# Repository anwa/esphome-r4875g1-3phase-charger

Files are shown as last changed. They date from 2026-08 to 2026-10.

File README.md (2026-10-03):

# 3-Phase Huawei R4875G1 Battery Charger Controller

ESPHome-based controller for three Huawei R4875G1 rectifiers operated as a coordinated three-phase battery charger with a common parallel DC output.

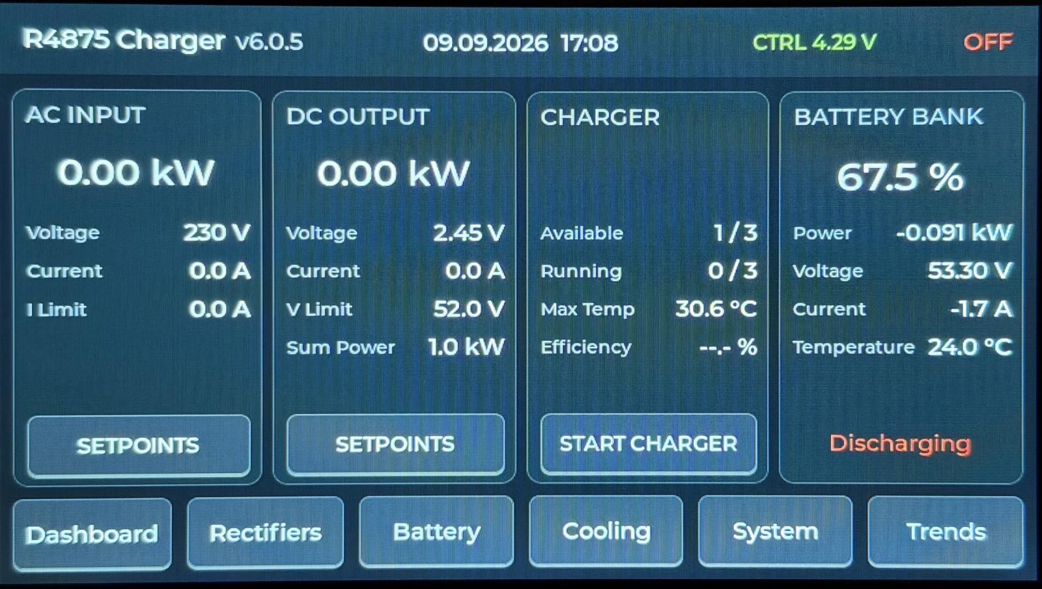
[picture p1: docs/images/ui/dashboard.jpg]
V6 shared charger dashboard


<p align="center"><em>Shared V6 Dashboard running on the Charger Controller.</em></p>

The V6 firmware generation uses two coordinated targets based on the **Waveshare ESP32-S3-Touch-LCD-7**:

- the Charger Controller, physically attached to the rectifiers and responsible for CAN, charger control, safety and local blackstart
- the Remote HMI, which uses the same shared Dashboard, Rectifiers, Battery, System, Cooling and Trends presentation while receiving authoritative charger state and sending HMI command requests through Home Assistant

Remote HMI charger commands use Home Assistant transport and remain subject to authoritative validation and execution by the Charger Controller.

A Remote HMI is paired with a Charger Controller through one configurable Home Assistant entity prefix. The individual Dashboard telemetry, setpoint and command entity IDs are derived from that prefix, so pairing another charger does not require editing every Home Assistant entity mapping.

The Charger Controller currently provides:

- local charger control
- CAN communication with three independent R4875G1 rectifiers
- automatic discovery and reconnect handling
- capability-aware current limiting
- thermal protection and derating
- network-independent local blackstart operation
- a 7-inch LVGL touchscreen interface
- a direct-GPIO backup rotary encoder for network-independent setpoint and charger power control
- external compartment cooling
- controller backup-battery monitoring
- Home Assistant solar-battery-bank monitoring
- Home Assistant, MQTT and ESPHome web integration

The charger core is intentionally designed to remain operational without Wi-Fi, Home Assistant, MQTT or Internet access.

For detailed runtime and state-machine behavior, see [`R4875G1_CONTROL_FLOWS.md`](R4875G1_CONTROL_FLOWS.md).

For package ownership and firmware architecture, see [`packages/README.md`](packages/README.md).

Repository development rules are defined in [`AGENTS.md`](AGENTS.md) and the [`rules/`](rules/) directory.

> [!WARNING]
> This project controls equipment connected to mains voltage and a high-current
> DC battery bus.
>
> Three Huawei R4875G1 rectifiers can represent roughly 12 kW of charging power
> and more than 200 A on a 48–58 V DC bus.
>
> Firmware is not a substitute for correctly designed fuses, breakers,
> disconnects, BMS protection, earthing, isolation, conductor sizing and other
> required electrical safety measures.

---

## System Architecture

The intended installation uses one rectifier per AC phase while all three DC outputs feed the same battery/DC bus.

```text
Three-phase AC
    │
    ├── L1 -> R4875G1 Unit 1 ──┐
    ├── L2 -> R4875G1 Unit 2 ──┼── Common DC bus / battery
    └── L3 -> R4875G1 Unit 3 ──┘
                 │
                 └── Shared CAN bus
                          │
                          ▼
              Waveshare ESP32-S3 Controller
```

All rectifiers use:

```text
CAN bit rate:       125 kbit/s
CAN identifiers:    29-bit extended
DC voltage command: shared
DC current command: common per-unit request
```

Each rectifier maintains its own communication, lifecycle, discovery, thermal and telemetry state.

---

## V6 Hardware Targets

The current firmware targets:

```text
Waveshare ESP32-S3-Touch-LCD-7
ESP32-S3 N16R8
16 MB Flash
8 MB PSRAM
7-inch 800 × 480 RGB LCD
GT911 capacitive touchscreen
CH422G onboard I/O expander
onboard CAN transceiver
```

The controller uses the onboard ESP32-S3 TWAI peripheral and CAN transceiver.
No external SN65HVD230 module is required by the V6 hardware.

### External I2C Architecture

The shared controller I2C bus uses:

```text
GPIO8  -> SDA
GPIO9  -> SCL
400 kHz
```

External I2C peripherals use a dedicated second physical I2C bus. This isolates their addresses from the Waveshare onboard CH422G and allows the onboard display/touch bus to remain at 400 kHz.

```text
ESP32-S3
│
├── Onboard I2C — GPIO8 / GPIO9 — 400 kHz
│   ├── CH422G
│   └── GT911 touchscreen
│
└── External I2C — GPIO44 / GPIO43
    ├── MCP23017 @ 0x20
    │   ├── GPA0 -> external fan power enable
    │   ├── GPA1 -> Cooling Fan 1 tachometer
    │   └── GPA2 -> Cooling Fan 2 tachometer
    ├── BME280 @ 0x76
    │   ├── rectifier-compartment temperature
    │   ├── rectifier-compartment humidity
    │   └── station pressure
    └── EMC2101 @ 0x4C
        ├── external fan PWM
        └── Cooling Fan 3 tachometer
```

The MCP23017 is used without a dedicated ESP32 interrupt line; INTA and INTB are intentionally left unconnected.

The backup rotary encoder is connected directly to the ESP32-S3 rather than through I2C:

```text
GPIO11 -> Encoder S1 / A
GPIO12 -> Encoder S2 / B
GPIO13 -> Encoder KEY
```

GPIO11, GPIO12 and GPIO13 are the Waveshare TF-card SPI pins, so the TF-card interface is unavailable while the backup encoder uses them.

The BME280 station pressure is exposed directly. A second pressure entity publishes the standard-atmosphere sea-level equivalent for the fixed 316 m installation altitude.

Unused MCP23017 pins remain available for future expansion.

---

## CAN Communication

The three Huawei rectifiers share one CAN bus.

The firmware implements independent per-unit communication state and explicit rectifier lifecycle handling:

```text
OFFLINE
   │
   │ CAN communication detected
   ▼
DISCOVERING
   │
   │ required discovery completed
   │ active setpoints restored
   ▼
ONLINE
```

A rectifier that loses valid communication returns to `OFFLINE`.

Normal high-rate telemetry polling is restricted to `ONLINE` units.

`OFFLINE` units are probed at a much lower rate using single-shot CAN transmission so an absent rectifier cannot continuously force the ESP32 TWAI controller toward `BUS_OFF`.

The firmware also implements explicit TWAI recovery if the complete physical CAN network disappears.

### Discovery

Discovery retrieves information including:

- static rectifier identification properties
- maximum DC-current capability
- shelf/address information

Discovery traffic is serialized so only one discovery operation owns the CAN bus at a time.

A successfully rediscovered unit receives the currently active DC voltage and current commands before its lifecycle returns to `ONLINE`.

---

## Charger Control

The controller manages three rectifiers as one coordinated charger while preserving independent per-unit safety and communication state.

Supported charger-wide controls include:

```text
Active DC voltage
Active per-unit DC current
Nominal three-unit DC power target
START
STOP
Fallback DC voltage
Fallback DC current
```

The nominal DC power target is converted into a common per-unit current request.

The requested current and the actually applied current are intentionally kept separate.

The final applied current is limited by:

```text
min(
    requested current,
    effective hardware capability,
    thermal current limit
)
```

This allows the requested charger target to remain unchanged while hardware or thermal protection temporarily reduces the current actually sent to the rectifiers.

---

## Capability-Aware Current Limiting

R4875G1 variants can report different maximum-current capabilities.

The controller therefore discovers the capability of each reachable unit and derives a safe shared limit.

The basic policy is:

```text
No reachable rectifier
    -> conservative fail-safe current ceiling

Reachable rectifier with unknown capability
    -> conservative fail-safe current ceiling

All reachable capabilities known
    -> effective ceiling = lowest reachable capability
```

Command scaling is derived independently from the detected rectifier capabilities so mixed-capability installations remain fail-safe.

A diagnostic entity reports capability mismatches between simultaneously reachable rectifiers.

---

## Thermal Protection

Each rectifier has an independent thermal state:

```text
NORMAL
WARNING_1
WARNING_2
LOCKOUT
```

The current configuration uses staged derating:

```text
70 °C -> first warning / reduced current
80 °C -> stronger current reduction
90 °C -> individual overtemperature shutdown
```

Hysteresis prevents rapid state oscillation while temperatures fall.

A thermal lockout is not cleared by missing or stale telemetry. Valid temperature data must confirm that the rectifier has returned to a safe temperature.

The shared thermal current ceiling is derived from the most restrictive active per-unit thermal state.

---

## Local Blackstart

Core charger operation is designed to remain available without network services.

Blackstart does not depend on:

```text
Home Assistant
MQTT
Wi-Fi
Internet access
```

Before a rectifier receives a START command, the controller verifies that it:

```text
is lifecycle ONLINE
has fresh CAN communication
reports explicit power state OFF
has valid output-temperature telemetry
is below the configured overtemperature trip threshold
has no active overtemperature lockout
```

Only units passing all checks receive the ON command.

STOP remains unrestricted.

This allows a partially available charger to remain controllable while preventing unknown or unsafe units from being started.

---

## Local User Interface

The controller uses the Waveshare 7-inch 800 × 480 RGB display with GT911 capacitive touch.

The display backlight is automatically disabled after the target-specific LVGL idle timeout while charger control and telemetry continue running normally. Touching and releasing the sleeping touchscreen always wakes the display without activating the control underneath the wake-up touch.

Each V6 target may optionally import its own Home Assistant occupancy/motion entity. Active motion wakes the display immediately and keeps the existing LVGL inactivity timer alive. When motion ends, the same configured idle timeout starts again. If no motion package is composed for a target, the original touch and idle-timeout behavior is unchanged. Home Assistant `unknown`, `unavailable` or connection loss is treated as no motion.

The LVGL interface contains six primary functional pages:

```text
Dashboard
Rectifiers
Battery
System
Cooling
Trends
```

The Rectifiers page also provides one shared hierarchical detail view for Units 1, 2 and 3.

### Dashboard

The Dashboard uses four equal-width overview cards for AC input, DC output, charger state and the external solar battery bank.

It provides charger-wide operating information including:

```text
AC input power
AC voltage
AC current
AC current limit
DC output power
DC voltage
combined DC current
active DC voltage limit
nominal total DC power target
available rectifier count
running rectifier count
highest rectifier output temperature
conversion efficiency
charger START/STOP state
solar battery-bank SOC
solar battery-bank power
solar battery-bank voltage
solar battery-bank current
solar battery-bank temperature
solar battery-bank operating state
```

AC and DC setpoints are edited through dedicated modal dialogs opened from the corresponding Dashboard cards.

Solar battery-bank information is imported from Home Assistant for monitoring only. Missing Home Assistant battery telemetry is shown explicitly and does not affect charger control or safety behavior.

### Rectifiers

The Rectifiers page provides one overview card for each unit.

Each rectifier maintains independent:

```text
lifecycle state
power state
CAN state
AC telemetry
DC telemetry
temperature
internal fan telemetry
```

Selecting a unit opens the shared Rectifier Detail page.

### Rectifier Detail

The detail view exposes extended per-unit information including:

```text
AC voltage
AC current
AC power
AC frequency
DC voltage
DC current
DC power
input temperature
output temperature
internal fan RPM
internal fan target duty
internal fan minimum duty
maximum-current capability
operating hours
fallback voltage
fallback current
```

One LVGL page is reused dynamically for all three rectifiers.

### Battery

The Battery page provides one monitoring card for each of four parallel solar-battery units. The same page layout and runtime are used by the Charger Controller and Remote HMI through the shared Battery UI model.

Each card displays:

```text
voltage
current
power
state of charge
temperature
cell drift
warning state
fault state
```

A consolidated per-battery status shows:

```text
HA OFFLINE
NO DATA
OK
WARNING
FAULT
```

`HA OFFLINE` indicates that no Home Assistant state-subscription connection is available.
`NO DATA` indicates that Home Assistant is connected but one or more required battery entities are unavailable or invalid.

Fault has priority over warning. Missing or invalid Home Assistant data is displayed explicitly instead of being treated as a healthy battery state.

All solar-battery telemetry is monitoring-only. It does not participate in charger setpoint calculation, START eligibility, thermal protection, CAN control or other charger safety decisions.

### Cooling

The Cooling page displays the shared rear-compartment environmental data and internal rectifier-fan telemetry.

External chassis-fan control is implemented independently by `packages/cooling.yaml`.

### System

The System page is shared by the Charger Controller and Remote HMI. It combines diagnostics measured locally on the active display controller with authoritative rectifier lifecycle state from the shared UI model.

```text
local network state
local Wi-Fi signal
local uptime
local CPU temperature
local memory/runtime information
local backup-battery voltage and state of charge
rectifier lifecycle status
```

On the Remote HMI, local device diagnostics remain available independently of Home Assistant. Rectifier state still follows the Charger Controller through Home Assistant and the shared UI-model boundary.

### Trends

Five independent sixty-minute ring buffers are maintained continuously:

```text
Combined DC Power
Combined DC Current
Average DC Voltage
Highest Rectifier Output Temperature
Rectifier Compartment Temperature
```

Sampling uses:

```text
10-second interval
360 samples
60-minute history
```

The chart time axis uses ten-minute divisions labeled from `-60 min` through `-10 min` and `now`.

Combined DC current and average DC voltage share one dual-axis chart. Current uses the left Y axis in amperes and voltage uses the right Y axis in volts, while both series use the same sixty-minute time base.

Invalid source values are preserved as gaps instead of being converted to artificial zero values.

---

## Backup Rotary Encoder and Blackstart Control

The Charger Controller uses a mechanical rotary encoder connected directly to ESP32-S3 GPIOs:

```text
GPIO11 -> Encoder S1 / A
GPIO12 -> Encoder S2 / B
GPIO13 -> Encoder KEY
```

The native ESPHome `rotary_encoder` component decodes the two quadrature channels with one output step per complete quadrature cycle. The physical encoder direction is mapped so clockwise rotation increases the active edit value.

The backup interaction is intentionally independent from normal touchscreen navigation:

```text
short press 1 -> edit charger-wide DC voltage
rotation      -> adjust voltage in 0.1 V steps
short press 2 -> edit nominal DC sum power
rotation      -> adjust power in 0.1 kW steps
short press 3 -> apply both pending setpoints

long press while idle -> request charger START or STOP
15 s inactivity       -> discard pending edits
```

Setpoint saves and charger power requests reuse the authoritative Charger Controller command paths. The encoder does not implement separate CAN or safety logic, and normal START eligibility remains authoritative.

The Controller-only LVGL overlay provides visual feedback while the display is available, but the encoder state machine and charger command path do not depend on touchscreen input, Home Assistant, MQTT or Internet access.

---

## External Cooling System

The external chassis cooling system is independent of the internal fans built into the Huawei rectifiers.

Three external fans are supported.

```text
MCP23017 GPA0 -> common fan-supply enable
MCP23017 GPA1 -> Fan 1 tachometer
MCP23017 GPA2 -> Fan 2 tachometer

EMC2101 PWM   -> common four-pin fan PWM
EMC2101 TACH  -> Fan 3 tachometer
```

Every fan retains its own tachometer signal.

The EMC2101 generates the shared hardware PWM signal at approximately:

```text
25.7 kHz
```

Cooling Fan 3 ventilates the rear rectifier compartment where the BME280 temperature/humidity/pressure sensor is installed.

### Web Controls and EMC2101 Telemetry

The ESPHome Web UI exposes the external cooling controls and EMC2101 telemetry:

```text
Cooling Fan Automatic
Cooling Fan Power
Cooling Fan Manual PWM
Cooling Fan PWM Actual
Cooling Fan Controller Temperature
Cooling Fan 1 RPM
Cooling Fan 2 RPM
Cooling Fan 3 RPM
```

`Cooling Fan Controller Temperature` reports the EMC2101 internal chip temperature. `Cooling Fan PWM Actual` reports the PWM duty cycle read back from the EMC2101 controller; it represents the programmed hardware setting rather than an independent measurement of the electrical PWM waveform.

Automatic and manual PWM control maintain separate state. While `Cooling Fan Automatic` is enabled, the compartment-temperature controller drives the EMC2101 PWM output directly and the manual PWM value remains stored without affecting the active output. When automatic mode is disabled, the stored `Cooling Fan Manual PWM` value is applied immediately and subsequent slider changes control the PWM output directly.

`Cooling Fan Power` controls the common external fan supply independently and remains available for manual operation when automatic mode is disabled.

### Automatic Cooling

Automatic cooling is enabled by default.

The current temperature curve is:

| Compartment temperature | Fan command |
| --- | ---: |
| `< 30 °C` | OFF / 0 % |
| `30–34.9 °C` | 35 % |
| `35–39.9 °C` | 45 % |
| `40–44.9 °C` | 60 % |
| `45–49.9 °C` | 80 % |
| `>= 50 °C` | 100 % |

Downward transitions use hysteresis.

If compartment-temperature telemetry becomes unavailable, the cooling system fails safe by enabling the external fans at 100 %.

---

## Local Display Backup Battery

Both V6 Waveshare display controllers support a local 1S lithium backup battery through the J3 battery connector.

The board provides an existing divider:

```text
VBAT -> 200 kΩ -> TP1 -> 100 kΩ -> GND
```

TP1 is externally connected to:

```text
J8 pin 3 / AD -> GPIO6
```

The ADC therefore sees one third of the battery voltage and the firmware restores the actual value using a factor of 3.

The measured voltage is filtered and exposed with a target-specific name:

```text
Controller Battery Voltage
Remote HMI Battery Voltage
```

A second sensor derives an approximate voltage-based state of charge:

```text
Controller Battery State of Charge
Remote HMI Battery State of Charge
```

The SOC value is intended for monitoring only. It is not a replacement for coulomb counting or a dedicated fuel-gauge IC.

---

## Solar Battery Bank Monitoring

Both V6 targets import monitoring data for an external four-unit solar battery bank from Home Assistant through the ESPHome native API.

All configurable Home Assistant entity mappings are centralized in:

```text
packages/shared/battery-bank.yaml
```

The imported aggregate bank data includes:

```text
voltage
current
power
state of charge
temperature
operating state
```

Each of the four individual battery units provides:

```text
voltage
current
power
state of charge
temperature
cell drift
warning state
fault state
```

The Home Assistant battery-bank and individual battery power entities are normalized internally from watts to kilowatts.

Battery warning and fault entities are imported as text states so `on`, `off`, `unknown` and `unavailable` remain distinguishable. After source validation, the shared Battery UI backend normalizes valid warning and fault states to boolean values in the target-neutral UI model.

Home Assistant battery telemetry is intentionally isolated from charger control. The charger remains locally operational when Wi-Fi or Home Assistant is unavailable.

---

## Network Interfaces

Network services provide additional monitoring and control but are not part of the local charger safety path.

The firmware integrates:

```text
ESPHome native API
MQTT
ESPHome Web Server
OTA
SNTP time synchronization
```

Home Assistant can therefore expose charger telemetry, diagnostics, setpoints and control entities while local operation remains independent.

---

## Firmware Architecture

The V6 generation is assembled from two root configurations plus shared and target-specific ESPHome packages.

```text
r4875g1-3phase-charger.yaml
r4875g1-remote-hmi.yaml
trend_helpers.h

packages/
├── version.yaml
├── controls.yaml
├── cooling.yaml
├── display.yaml
├── rectifier-shared.yaml
├── rectifier-unit.yaml
│
├── shared/
│   ├── core.yaml
│   ├── hardware.yaml
│   ├── local-diagnostics.yaml
│   ├── ui-model.yaml
│   ├── ui-contract.yaml
│   └── battery-monitoring.yaml
│
├── controller/
│   ├── hardware.yaml
│   ├── mqtt.yaml
│   ├── ui-backend.yaml
│   ├── ui-rectifier-backend.yaml
│   └── ui-commands.yaml
│
├── remote-hmi/
│   ├── connection-status.yaml
│   ├── ha-entity-map.yaml
│   ├── ha-backend.yaml
│   ├── rectifier-backend.yaml
│   └── ui-commands.yaml
│
├── display/
│   ├── shared-hmi.yaml
│   ├── shared-dashboard.yaml
│   ├── shared-rectifiers.yaml
│   ├── shared-battery.yaml
│   ├── shared-system.yaml
│   ├── shared-cooling.yaml
│   ├── shared-trends.yaml
│   ├── shared-navigation.yaml
│   └── pages/
│
└── rectifier-can/
    └── parameterized CAN receive handlers
```

### Package Responsibilities

| Package | Responsibility |
| --- | --- |
| `version.yaml` | coordinated V6 firmware version source of truth |
| `shared/core.yaml` | shared ESP32 platform, network, API, web, OTA and time services |
| `shared/hardware.yaml` | shared Waveshare board peripherals and local backup-battery monitoring |
| `shared/ui-model.yaml` | target-neutral state consumed by the shared HMI |
| `shared/battery-monitoring.yaml` | shared Home Assistant solar-battery monitoring and UI-model backends |
| `controller/hardware.yaml` | Charger Controller CAN, external I2C and charger-side hardware |
| `controller/ui-backend.yaml` | publishes authoritative local charger state into the shared UI model |
| `controller/ui-commands.yaml` | executes shared HMI command intents on the Charger Controller |
| `remote-hmi/ha-backend.yaml` | imports authoritative Charger Controller state through Home Assistant |
| `remote-hmi/ui-commands.yaml` | transports shared HMI command intents through Home Assistant |
| `remote-hmi/connection-status.yaml` | persistent Remote HMI Home Assistant connectivity presentation |
| `controls.yaml` | charger-wide user setpoints and controls |
| `cooling.yaml` | Charger Controller external chassis-fan control and RPM monitoring |
| `display.yaml` | Charger Controller aggregation of the shared display packages |
| `display/shared-hmi.yaml` | shared display infrastructure, presentation state, header and local trend history |
| `display/shared-*.yaml` | shared page presentation/runtime compositions for both V6 targets |
| `display/shared-navigation.yaml` | shared six-page bottom navigation |
| `rectifier-shared.yaml` | shared lifecycle, safety, discovery, CAN scheduling and control |
| `rectifier-unit.yaml` | parameterized per-unit state and telemetry |
| `rectifier-can/*.yaml` | parameterized CAN receive handlers |
| `trend_helpers.h` | native LVGL chart declarations used by the shared Trends runtime |

The detailed ownership model is documented in [`packages/README.md`](packages/README.md).

---

## Display Architecture

Both V6 targets use the same shared LVGL presentation. Target-specific backends translate their native state into the shared UI model, and shared page runtimes consume only that target-neutral model.

```text
                         Shared LVGL HMI
                               │
                               ▼
                       Shared UI model
                               │
                ┌──────────────┴──────────────┐
                ▼                             ▼
      Charger Controller backend       Remote HMI backend
                │                             │
                ▼                             ▼
       Local runtime / CAN          Home Assistant entities
```

The shared display composition contains:

```text
shared-hmi
shared-dashboard
shared-rectifiers
shared-battery
shared-system
shared-cooling
shared-trends
shared-navigation
```

Only the currently visible page receives normal page-specific display refreshes. Persistent header state, command-transition state, local backup-battery presentation and local trend sampling continue independently on each target.

---

## Building

The two V6 ESPHome root configurations are:

```text
r4875g1-3phase-charger.yaml
r4875g1-remote-hmi.yaml
```

Validate and compile the Charger Controller with:

```bash
esphome config r4875g1-3phase-charger.yaml
esphome compile r4875g1-3phase-charger.yaml
```

Validate and compile the Remote HMI with:

```bash
esphome config r4875g1-remote-hmi.yaml
esphome compile r4875g1-remote-hmi.yaml
```

Changes to shared V6 HMI code or shared target contracts must be validated against both targets. Hardware-dependent behavior should also be tested on the affected physical target after successful compilation.

---

## Versioning

The firmware version has exactly one source of truth:

```text
packages/version.yaml
```

Do not duplicate the current firmware version in documentation.

Version changes follow:

```text
rules/versioning.md
```

Pure documentation and repository-cleanup changes do not require a firmware version increment unless they also change runtime behavior.

---

## Repository Development Rules

AI-assisted and human development follows the repository rules in:

```text
AGENTS.md
rules/
```

`AGENTS.md` is the entry point for agents.

All human-readable repository content created or substantially modified by the project is written in English.

The repository rules define:

```text
development workflow
Git workflow
versioning
documentation
YAML comment style
```

---

## V4 Hardware Variant

The previous ESP32-S3-DevKitC-1 hardware implementation remains maintained separately on:

```text
v4-maintenance
```

V4 is a permanent hardware variant rather than the active V6 controller target.

Changes that are genuinely shared between both hardware generations may be ported when appropriate, but V6-specific display, I/O and hardware assumptions must not be applied blindly to the V4 branch.

---

## Related Projects and References

The following projects and documentation were particularly useful during the development and verification of the R4875G1 Charger Controller:

- [CAN-BUS-control-R4875G1-with-ESPHome-and-MQTT](https://github.com/mjpalmowski/CAN-BUS-control-R4875G1-with-ESPHome-and-MQTT)
  This project originally grew from the Huawei R4875G1 CAN and ESPHome work published by **mjpalmowski**. It provided important groundwork for Huawei CAN protocol research, telemetry decoding, control commands, property and capability discovery, and ESPHome integration.

- [patagonaa/huawei-r48xx](https://github.com/patagonaa/huawei-r48xx)
  Extensive R48xx-series documentation covering connectors, mechanical models, CAN protocol details, register behavior, software-address negotiation and model-specific observations. Its 3D PSU and case models also provided useful reference geometry for the charger's mechanical enclosure development.

- [craigpeacock/Huawei_R4850G2_CAN](https://github.com/craigpeacock/Huawei_R4850G2_CAN)
  Earlier public CAN protocol research for Huawei R48xx rectifiers and an additional useful reference while validating protocol behavior.

The Controller implementation in this repository has since evolved into a dedicated three-unit charger with independent per-unit lifecycle management, local and network-independent control, automatic CAN recovery, capability-aware current limiting, thermal protection, local blackstart operation, a shared touchscreen HMI architecture and external cooling management.

The implementation is independently maintained and contains additional multi-rectifier lifecycle, reconnect, capability, thermal, blackstart and HMI behavior specific to this project.

---

## Disclaimer

This repository is provided for development and experimentation with Huawei R4875G1 rectifiers.

Anyone building or operating hardware based on this project is responsible for the electrical, thermal and mechanical safety of the resulting system.

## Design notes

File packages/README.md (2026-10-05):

# Firmware Package Architecture

This directory contains the modular ESPHome implementation of the three-phase Huawei R4875G1 charger controller.

The V6 architecture contains two ESPHome root configurations:

```text
../r4875g1-3phase-charger.yaml
../r4875g1-remote-hmi.yaml
```

r4875g1-3phase-charger.yaml assembles the locally attached Charger Controller.

r4875g1-remote-hmi.yaml assembles the Remote HMI target without charger-side CAN or external peripherals.

For project-level hardware, operation and safety documentation, see:

```text
../README.md
```

For detailed rectifier lifecycle and control-flow documentation, see:

```text
../R4875G1_CONTROL_FLOWS.md
```

The firmware version is intentionally not duplicated here.
`version.yaml` is the single source of truth.

---

## Package Structure

```text
packages/
├── version.yaml
│
├── shared/
│   ├── ui-rectifier-unit.yaml
│   ├── ui-battery-unit.yaml
│   ├── ui-contract.yaml
│   ├── battery-bank.yaml
│   ├── battery-monitoring.yaml
│   ├── battery-ui-backend.yaml
│   ├── battery-ui-unit-backend.yaml
│   ├── core.yaml
│   ├── local-diagnostics.yaml
│   ├── hardware.yaml
│   └── ui-model.yaml
│
├── controller/
│   ├── encoder-ui.yaml
│   ├── encoder.yaml
│   ├── environment.yaml
│   ├── ha-contract.yaml
│   ├── hardware.yaml
│   ├── mqtt.yaml
│   ├── ui-backend.yaml
│   ├── ui-commands.yaml
│   └── ui-rectifier-backend.yaml
│
├── remote-hmi/
│   ├── connection-status.yaml
│   ├── ha-entity-map.yaml
│   ├── ha-backend.yaml
│   ├── rectifier-backend.yaml
│   └── ui-commands.yaml
│
├── controls.yaml
├── cooling.yaml
├── display.yaml
├── rectifier-shared.yaml
├── rectifier-unit.yaml
├── README.md
│
├── display/
│   ├── ui-state.yaml
│   ├── trend-state.yaml
│   ├── chart-support.yaml
│   ├── homeassistant-motion.yaml
│   ├── header-ui.yaml
│   ├── dashboard-ui.yaml
│   ├── dashboard-command-state.yaml
│   ├── rectifiers-ui.yaml
│   ├── battery-ui.yaml
│   ├── cooling-ui.yaml
│   ├── system-ui.yaml
│   ├── trends-ui.yaml
│   ├── fallback-dialog.yaml
│   ├── rectifier-power-dialogs.yaml
│   ├── shared-rectifiers.yaml
│   ├── shared-battery.yaml
│   ├── shared-cooling.yaml
│   ├── shared-system.yaml
│   ├── shared-trends.yaml
│   ├── shared-navigation.yaml
│   ├── hardware.yaml
│   ├── theme.yaml
│   ├── header.yaml
│   ├── command-state.yaml
│   ├── battery.yaml
│   ├── dashboard.yaml
│   ├── rectifiers.yaml
│   ├── rectifier-detail.yaml
│   ├── cooling.yaml
│   ├── system.yaml
│   ├── trends.yaml
│   ├── shared-hmi.yaml
│   ├── shared-dashboard.yaml
│   ├── local-battery-header.yaml
│   │
│   └── pages/
│       ├── dashboard.yaml
│       ├── rectifiers.yaml
│       ├── rectifier-detail.yaml
│       ├── battery.yaml
│       ├── cooling.yaml
│       ├── system.yaml
│       └── trends.yaml
│
└── rectifier-can/
    ├── property-start.yaml
    ├── property-end.yaml
    ├── cyclic-telemetry.yaml
    ├── alarm-status.yaml
    ├── fan-telemetry.yaml
    ├── address-data.yaml
    └── power-state.yaml
```

---

## Ownership Principles

Package ownership is intentionally separated so that hardware, shared charger logic, per-unit state, display layout and periodic display updates remain independent.

The main ownership boundaries are:

```text
shared/core.yaml
    target-neutral ESP32-S3 platform and network services

shared/hardware.yaml
    target-neutral Waveshare board peripherals

shared/local-diagnostics.yaml
    target-local network, ESP32 and runtime diagnostics shared by both V6 targets

shared/ui-model.yaml
    target-neutral aggregate state contract consumed by the HMI

shared/ui-contract.yaml
    shared HMI command ranges used by both V6 targets

shared/battery-bank.yaml
    shared Home Assistant solar-battery telemetry import and availability state

shared/battery-monitoring.yaml
    composes the shared battery source and aggregate/per-unit UI-model backends

shared/battery-ui-backend.yaml
    publishes validated aggregate battery-bank monitoring state into the shared UI model

shared/battery-ui-unit-backend.yaml
    publishes one validated battery unit into the shared per-unit UI model

shared/ui-battery-unit.yaml
    parameterized target-neutral UI state for one solar-battery unit

shared/ui-rectifier-unit.yaml
    parameterized target-neutral UI state for one rectifier

controller/hardware.yaml
    Charger Controller buses and charger-side peripherals

controller/environment.yaml
    Charger Controller rectifier-compartment environment sensing

controller/ha-contract.yaml
    publishes the explicit Home Assistant charger-contract version used for compatible Charger Instance discovery

controller/mqtt.yaml
    Charger Controller MQTT transport

controller/ui-backend.yaml
    publishes authoritative local charger state into the shared UI model

controller/ui-commands.yaml
    executes shared UI command intents through local Charger Controller entities

controller/encoder.yaml
    owns the network-independent local backup encoder state machine and control requests

controller/encoder-ui.yaml
    provides Controller-only LVGL feedback for backup encoder interaction

controller/ui-rectifier-backend.yaml
    publishes one local rectifier into the shared per-unit UI model

remote-hmi/connection-status.yaml
    exposes persistent Remote HMI Home Assistant / charger-data connectivity in the shared header

remote-hmi/ha-entity-map.yaml
    derives paired Charger Controller Home Assistant entities from one configurable prefix

remote-hmi/ha-backend.yaml
    imports authoritative Charger Controller state through Home Assistant

remote-hmi/ui-commands.yaml
    transports shared UI command intents to the Charger Controller through Home Assistant

remote-hmi/rectifier-backend.yaml
    imports one authoritative rectifier state through Home Assistant

controls.yaml
    charger-wide user setpoints and controls

cooling.yaml
    external chassis cooling

display.yaml
    display package aggregation

rectifier-shared.yaml
    cross-unit lifecycle, safety and CAN scheduling

rectifier-unit.yaml
    parameterized per-unit state and telemetry

display/*.yaml
    persistent and page-specific display runtime

display/ui-state.yaml
    shared LVGL presentation, navigation and command-pending state

display/trend-state.yaml
    shared local 60-minute HMI trend history sampled from the target-neutral UI model

display/chart-support.yaml
    shared LVGL chart build support used by both V6 HMI targets

display/homeassistant-motion.yaml
    optional target-specific Home Assistant motion source for shared display activity

display/header-ui.yaml
    shared persistent header layout

display/dashboard-ui.yaml
    shared Dashboard page and Dashboard-specific dialogs

display/dashboard-command-state.yaml
    shared charger-wide START/STOP presentation state

display/command-state.yaml
    shared per-rectifier START/STOP pending-state resolution

display/shared-hmi.yaml
    shared display infrastructure, chart support, persistent header, trend history and presentation state

display/shared-dashboard.yaml
    shared Dashboard presentation and runtime consumed by both V6 firmware targets

display/shared-rectifiers.yaml
    shared Rectifiers composition consumed by both V6 firmware targets

display/shared-battery.yaml
    shared Battery presentation and runtime consumed by both V6 firmware targets

display/shared-cooling.yaml
    shared Cooling presentation and runtime consumed by both V6 firmware targets

display/shared-system.yaml
    shared System presentation and runtime consumed by both V6 firmware targets

display/shared-trends.yaml
    shared Trends presentation and chart runtime consumed by both V6 firmware targets

display/shared-navigation.yaml
    shared Dashboard, Rectifiers, Battery, System, Cooling and Trends bottom navigation

display/rectifiers-ui.yaml
    shared Rectifiers Overview and Detail presentation

display/battery-ui.yaml
    shared Battery page presentation

display/cooling-ui.yaml
    shared Cooling page presentation

display/trends-ui.yaml
    shared Trends page presentation

display/cooling.yaml
    shared Cooling page runtime

display/system-ui.yaml
    shared System page presentation

display/system.yaml
    shared local-target diagnostics and rectifier-status page runtime

display/trends.yaml
    shared native LVGL Trends chart runtime

display/fallback-dialog.yaml
    shared fallback-setpoint dialog

display/rectifier-power-dialogs.yaml
    parameterized shared per-unit START/STOP dialogs

display/local-battery-header.yaml
    shared local display-controller backup-battery header runtime

display/pages/*.yaml
    static LVGL page layouts

rectifier-can/*.yaml
    parameterized CAN receive fragments

```
A package SHOULD own one coherent responsibility and SHOULD NOT duplicate runtime state or hardware definitions owned elsewhere.

---

## `version.yaml`

`version.yaml` is the only source of truth for the firmware version.

The value is consumed by the firmware project metadata and user-interface components that display the current version.

Versioning policy is defined in:

```text
../rules/versioning.md
```

Documentation-only and repository-cleanup commits do not require a firmware version change unless runtime behavior also changes.

---

## `shared/core.yaml`

Owns target-neutral ESP32-S3 platform and network infrastructure shared by the Charger Controller and Remote HMI.

Responsibilities include:

- ESP32-S3 platform and framework configuration
- Flash and PSRAM configuration
- logging
- Wi-Fi
- ESPHome native API
- web server
- OTA
- time synchronization
- ESPHome debug-component support

Target-specific command and telemetry transports do not belong in this package.

---

## `shared/local-diagnostics.yaml`

Owns target-local diagnostic entities that are common to the Charger Controller and Remote HMI.

Responsibilities include:

- heap and PSRAM diagnostics
- maximum free heap block
- ESPHome loop time
- CPU frequency and temperature
- device uptime
- Wi-Fi RSSI and IP address
- ESPHome version
- device information and reset reason

The diagnostics describe the ESP32 running the current firmware target. They do not represent charger operational state and do not participate in charger control or safety.

---

## `shared/hardware.yaml`

Owns physical Waveshare ESP32-S3-Touch-LCD-7 hardware that is independent of the charger-side backend.

Responsibilities include:

- onboard I2C bus
- GT911 touchscreen
- CH422G onboard I/O expander
- local display-controller backup-battery ADC and SOC estimate

This package contains board hardware that can be reused by multiple firmware targets without requiring charger-side peripherals. Local backup-battery entity names use the target's `diagnostics_device_label`, while the internal runtime IDs remain target-neutral.

---

## `shared/ui-model.yaml`

Owns the target-neutral runtime state consumed by shared HMI code.

The model isolates LVGL presentation from the source of charger data. Charger Controller and Remote HMI backends publish into the same model IDs so shared display code does not need target-specific telemetry paths.

The current model includes Dashboard AC/DC aggregate telemetry, active and fallback charger setpoints, rectifier availability/run state, per-rectifier overview and detail telemetry, highest output temperature, conversion efficiency and aggregate solar-battery-bank monitoring state. Parameterized per-battery monitoring state is defined in `shared/ui-battery-unit.yaml`.

---

## `controller/hardware.yaml`

Owns physical hardware that exists only on the Charger Controller.

Responsibilities include:

- dedicated charger-side external I2C bus
- MCP23017 external I/O expander for external fan power and tachometer signals
- direct-GPIO backup rotary-encoder inputs
- USB/CAN routing selection
- ESP32-S3 TWAI / onboard CAN interface

The MCP23017 INTA and INTB outputs are intentionally unconnected. The direct encoder uses GPIO11, GPIO12 and GPIO13, which makes the Waveshare TF-card interface unavailable on the Charger Controller.

---

## `controller/environment.yaml`

Owns the Charger Controller rear-compartment environmental sensor.

Responsibilities include:

- BME280 access on the dedicated external I2C bus
- rectifier-compartment temperature and humidity
- physical station pressure
- standard-atmosphere sea-level pressure correction for the configured 316 m installation altitude

The established compartment temperature and humidity IDs remain unchanged so cooling control and the Controller UI backend continue to consume the same local interface.

---

## `controller/mqtt.yaml`

Owns the Charger Controller MQTT transport.

MQTT remains optional for charger operation and is independent from the native ESPHome API used by Home Assistant.

The Remote HMI does not require this package.

---

## `controller/ui-backend.yaml`

Owns translation from authoritative local Charger Controller runtime state into the shared UI model.

This backend does not own charger state itself. The existing controller runtime remains authoritative.

---

## `controller/ui-commands.yaml`

Implements the shared HMI command interface for the Charger Controller target.

The command scripts translate target-neutral Dashboard, fallback-setpoint and per-rectifier command intent into the existing local ESPHome controls. Charger safety, validation and CAN execution remain owned by the existing Controller entities and scripts.

---

## `controller/encoder.yaml`

Owns the Charger Controller backup rotary-encoder state machine.

The encoder provides local DC-voltage and nominal DC sum-power editing plus deliberate long-press charger START/STOP requests. It reuses the existing `ui_command_*` command paths rather than duplicating charger safety or CAN logic.

The control state is independent from normal LVGL navigation and from Home Assistant, MQTT and Internet connectivity.

---

## `controller/encoder-ui.yaml`

Owns the Controller-only LVGL feedback overlay for backup encoder interaction.

The overlay blocks touchscreen controls while an encoder setpoint edit is active and shows short status feedback after saved setpoints or charger power requests. It is presentation-only; charger-control authority remains outside LVGL.

---

## `remote-hmi/connection-status.yaml`

Provides persistent Remote-HMI-specific connectivity presentation in the target-specific status area of the shared persistent header.

The status clearly indicates whether authoritative Charger Controller data is currently available through Home Assistant across the shared HMI pages. It does not duplicate charger state or safety logic.

---

## `remote-hmi/ha-entity-map.yaml`

Owns the Home Assistant entity mapping for the Charger Controller paired with a Remote HMI.

The Remote HMI root defines one installation-specific `ha_charger_entity_prefix`. The entity map derives the Dashboard telemetry, setpoint, charger-wide command, per-rectifier state and per-rectifier command entity IDs from that prefix.

This keeps Home Assistant entity naming out of the state and command backends and allows another Charger Controller to be paired by changing one configuration value.

The same prefix is used for all three rectifier backends, so per-unit Home Assistant mappings do not require separate installation-specific configuration.

The configured prefix must match the actual Home Assistant entity IDs. Home Assistant may preserve existing entity IDs after an ESPHome device is renamed, so the prefix is not inferred dynamically from the current device name.

---

## `remote-hmi/ha-backend.yaml`

Owns the Remote HMI Home Assistant transport.

It imports authoritative Charger Controller entities from Home Assistant and publishes them into the shared UI model. Shared LVGL code therefore consumes the same `ui_model_*` entities on both firmware targets.

The backend supplies Charger-side Dashboard telemetry, active and fallback setpoint state required by the shared UI model. Charger command transport remains separate.

Loss of the Home Assistant state-subscription connection invalidates Remote HMI charger state so stale values cannot appear as live telemetry.

Home Assistant entity IDs are supplied by `remote-hmi/ha-entity-map.yaml` rather than being embedded in the backend.

---

## `remote-hmi/ui-commands.yaml`

Implements the shared HMI command interface for the Remote HMI target.

The backend sends charger-wide, fallback-setpoint and per-rectifier command requests through Home Assistant to the Charger Controller entities. It does not duplicate safety logic and does not treat a request as confirmed charger state.

The shared UI model remains authoritative for displayed command results after Home Assistant reports the resulting Charger Controller state.

Command target entity IDs are supplied by `remote-hmi/ha-entity-map.yaml`.

---

## Charger Controller I2C Topology

The controller uses two independent physical I2C buses. The onboard bus is reserved for Waveshare peripherals, while external peripherals use a dedicated bus to avoid address collisions with the onboard CH422G.

```text
ESP32-S3
│
├── Onboard I2C bus
│   ├── SDA -> GPIO8
│   ├── SCL -> GPIO9
│   ├── CH422G
│   └── GT911 touchscreen
│
└── External I2C bus
    ├── SDA -> GPIO44
    ├── SCL -> GPIO43
    ├── MCP23017 @ 0x20
    ├── BME280 @ 0x76
    └── EMC2101 @ 0x4C
```

The onboard I2C bus is configured in `shared/hardware.yaml`. The charger-side external I2C bus and MCP23017 are configured in `controller/hardware.yaml`. The BME280 environment sensor is configured in `controller/environment.yaml`, while the EMC2101 fan controller is configured in `cooling.yaml`.

### Charger Controller Local I/O Allocation

The backup rotary encoder is connected directly to the ESP32-S3:

```text
GPIO11 -> Encoder S1 / A
GPIO12 -> Encoder S2 / B
GPIO13 -> Encoder KEY
```

The MCP23017 is reserved for external cooling-fan I/O:

```text
GPA0 -> external cooling-fan supply enable
GPA1 -> Cooling Fan 1 tachometer
GPA2 -> Cooling Fan 2 tachometer
INTA -> not connected
INTB -> not connected
```

The encoder hardware is defined in `controller/hardware.yaml`, while its local control state machine is owned by `controller/encoder.yaml`.

---

## `controls.yaml`

Owns charger-wide user-facing setpoints and controls.

This includes values such as:

- active DC voltage target
- charger power target
- fallback voltage
- fallback current
- charger-wide START/STOP controls

Shared controls SHOULD express user intent.

Safety limiting, capability limiting and per-unit CAN command transmission are implemented in the rectifier control packages rather than directly in
`controls.yaml`.

---

## `cooling.yaml`

Owns the external chassis cooling system.

This subsystem is separate from the internal fans built into the Huawei rectifiers.

Current external cooling hardware:

```text
MCP23017 GPA0 -> common fan-supply enable
MCP23017 GPA1 -> Cooling Fan 1 tachometer
MCP23017 GPA2 -> Cooling Fan 2 tachometer

EMC2101 PWM   -> common four-pin fan PWM
EMC2101 TACH  -> Cooling Fan 3 tachometer

BME280        -> rear-compartment temperature, humidity and pressure
```

Responsibilities include:

- EMC2101 fan-controller configuration
- EMC2101 internal-temperature and PWM-duty telemetry
- common external fan PWM
- persistent manual PWM setpoint
- common fan-supply enable
- three independent RPM measurements
- automatic temperature-based cooling
- manual fan-power and PWM control

Automatic and manual PWM ownership is intentionally separated. Automatic mode writes the temperature-derived duty cycle directly to the EMC2101 output without modifying the stored manual PWM setpoint. Disabling automatic mode immediately applies the stored manual setpoint, and subsequent manual slider changes control the output directly.

`Cooling Fan PWM Actual` is the EMC2101 duty-cycle register readback and therefore represents the controller's programmed PWM setting rather than an independently measured waveform.

Cooling Fan 3 ventilates the rear rectifier compartment monitored by the BME280.

Automatic cooling fails safe to enabled fan power and maximum PWM if the compartment temperature becomes unavailable.

---

## `shared/battery-bank.yaml`

Owns Home Assistant telemetry import for the external solar battery bank.

The package centralizes all configurable Home Assistant entity mappings so display code does not contain installation-specific entity IDs.

Responsibilities include:

- aggregate battery-bank voltage, current, power, state of charge, temperature and operating state
- per-battery voltage, current, power, state of charge, temperature and cell drift
- per-battery warning and fault states
- power-unit normalization for imported battery telemetry
- Home Assistant connection and data-availability states

Warning and fault entities are intentionally imported as text so unavailable source data remains distinguishable from a genuine inactive warning or fault.

This package is monitoring-only and MUST NOT participate in charger control, CAN commands, lifecycle decisions or safety limits.

---

## `shared/battery-monitoring.yaml`

Composes the Home Assistant battery source, aggregate UI backend and four parameterized per-unit UI-model/backend pairs used by both V6 targets.

The aggregate battery-bank model remains part of `shared/ui-model.yaml`; per-unit Battery-page state is provided by `shared/ui-battery-unit.yaml`.

---

## `shared/ui-battery-unit.yaml`

Defines target-neutral monitoring state for one solar-battery unit.

Each instance provides per-unit data availability, warning/fault state, voltage, current, power, state of charge, temperature and cell drift.

---

## `shared/battery-ui-backend.yaml`

Publishes validated aggregate battery-bank monitoring state into the shared UI model and exposes the common Home Assistant battery-source connectivity state.

Unavailable aggregate battery data is invalidated before it reaches shared LVGL code so stale monitoring values cannot appear as live state.

---

## `shared/battery-ui-unit-backend.yaml`

Publishes one validated battery unit into the parameterized per-unit UI model.

Both V6 targets use the same Home Assistant battery source package, so this backend is shared rather than target-specific. Raw warning and fault text states are validated by `shared/battery-bank.yaml` and normalized to boolean UI-model state here.

---

# Rectifier Architecture

The rectifier implementation is split into shared and parameterized packages.

```text
rectifier-shared.yaml
        │
        ├── shared lifecycle and safety state
        ├── discovery serialization
        ├── capability evaluation
        ├── thermal limiting
        ├── CAN scheduling
        └── charger-wide command routing

rectifier-unit.yaml
        │
        └── instantiated once for each rectifier

rectifier-can/*.yaml
        │
        └── parameterized CAN receive fragments
```

---

## `rectifier-shared.yaml`

Owns cross-unit state and behavior shared by all three rectifiers.

Major responsibilities include:

- rectifier lifecycle coordination
- communication reconciliation
- TWAI recovery handling
- serialized discovery
- low-rate OFFLINE probing
- high-rate ONLINE polling
- capability-aware current limiting
- shared protocol scaling
- thermal current limiting
- active setpoint routing
- blackstart START/STOP sequences
- periodic setpoint refresh

### Lifecycle

Each rectifier uses:

```text
OFFLINE
DISCOVERING
ONLINE
```

Normal cyclic and fan telemetry polling is restricted to `ONLINE` units.

`OFFLINE` units are probed sparsely so absent peers cannot continuously generate high-rate failed CAN transmissions.

### Shared Current Limit

The effective current ceiling is derived from currently reachable rectifiers.

If any reachable unit has an unknown maximum-current capability, the conservative fail-safe ceiling is used.

When all reachable capabilities are known, the lowest reachable capability becomes the shared hardware ceiling.

The thermal ceiling is applied independently.

Final CAN current commands therefore use the most restrictive relevant limit.

---

## `rectifier-unit.yaml`

Parameterized package instantiated once for each R4875G1.

The main configuration provides:

```text
ru_unit = 1
ru_unit = 2
ru_unit = 3
```

Each instance owns per-unit:

- CAN watchdog timestamp
- lifecycle state
- thermal state
- overtemperature lockout
- discovery flags
- discovery counters
- property buffer
- telemetry sensors
- static identification sensors
- maximum-current capability
- unit-specific discovery scripts
- unit-specific START control

Public IDs intentionally resolve to stable per-unit names.

Shared cross-unit policy does not belong in this package.

---

## `rectifier-can/`

Contains parameterized CAN receive fragments used by the shared CAN interface.

Every fragment receives at least:

```text
ru_unit
```

as a substitution.

### `property-start.yaml`

Handles:

```text
0x108${ru_unit}D27F
```

Starts and accumulates the multi-frame ASCII static-property response.

### `property-end.yaml`

Handles:

```text
0x108${ru_unit}D27E
```

Completes the property response, parses required keys and marks static-property discovery complete only when all required values have been decoded.

### `cyclic-telemetry.yaml`

Handles:

```text
0x108${ru_unit}407F
```

Decodes selector-based operational telemetry such as:

- AC power
- AC frequency
- AC current
- AC voltage
- DC power
- DC voltage
- DC current
- rectifier-reported efficiency
- temperatures
- operating hours
- rectifier-reported current setpoint

### `alarm-status.yaml`

Handles:

```text
0x108${ru_unit}407E
```

Decodes the 32-bit Huawei register `0x0183` alarm/status word.

The handler publishes:

- an exact hexadecimal raw status value
- one diagnostic binary sensor for each documented status bit 0-31
- Huawei reference meanings for all documented bits

Only the subset reproduced safely on the R4875G1 is marked as verified or observed. The remaining bit meanings follow the Huawei R48xx protocol documentation and remain diagnostic-only until independently confirmed on the R4875G1.

Alarm/status telemetry does not participate in Charger safety or control decisions.

### `fan-telemetry.yaml`

Handles:

```text
0x108${ru_unit}827E
```

Decodes internal rectifier-fan telemetry:

- minimum duty
- target duty
- fan RPM

### `address-data.yaml`

Handles:

```text
0x108${ru_unit}507E
```

Decodes shelf/slot address data used during discovery.

### `power-state.yaml`

Handles:

```text
0x100${ru_unit}117E
```

Publishes:

- rectifier ON/OFF/ERROR state
- alternate DC-current freshness telemetry

---

# Display Architecture

The V6 display implementation uses one shared presentation architecture for the Charger Controller and Remote HMI. Static LVGL layout, page runtime, trend history and bottom navigation are shared; target-specific telemetry acquisition and command transport remain behind the shared UI-model and `ui_command_*` boundaries.

The Charger Controller composes the shared display stack through `display.yaml`. The Remote HMI root composes the same shared packages directly.

The current architecture is:

```text
display/shared-hmi.yaml
    shared display hardware, theme, chart support, UI state,
    local trend history and persistent header

display/shared-dashboard.yaml
display/shared-rectifiers.yaml
display/shared-battery.yaml
display/shared-cooling.yaml
display/shared-system.yaml
display/shared-trends.yaml
    page-specific shared presentation and runtime

display/shared-navigation.yaml
    shared six-page bottom navigation
```

Only the currently visible page receives normal page-specific display refreshes. Persistent header state, local backup-battery presentation, command-transition state and local trend sampling continue independently.

---

## `display.yaml`

Charger Controller display-package aggregator.

It composes the same shared HMI infrastructure, six shared main pages and shared bottom navigation used by the Remote HMI. The Remote HMI root composes those shared packages directly because it also owns target-specific Home Assistant backends and connectivity presentation.

It should contain package composition rather than page logic.

---

## `display/hardware.yaml`

Owns the Waveshare RGB display, backlight and LVGL hardware integration shared by both V6 targets.

Responsibilities include:

- 800 × 480 RGB panel configuration
- framebuffer configuration
- LVGL display binding
- shared touchscreen binding
- backlight control
- boot-time display/LVGL ordering behind network recovery services

The physical GT911 touchscreen is owned by `shared/hardware.yaml`; `display/hardware.yaml` binds that shared touchscreen to LVGL.

The RGB display and LVGL use explicit setup priorities below Wi-Fi and the API/OTA services. This allows networking to reserve scarce internal and DMA-capable memory before the display stack starts while preserving the required display-before-LVGL dependency.

---

## `display/theme.yaml`

Owns reusable presentation definitions including:

- fonts
- card styles
- page styles
- header styles
- navigation styles
- common LVGL defaults

It should not own live telemetry or control-state logic.

---

## `display/shared-hmi.yaml`

Owns common display infrastructure and persistent presentation state used by all shared pages.

Responsibilities include:

- RGB display/LVGL integration
- shared theme
- native LVGL chart support
- active-page and presentation state
- local sixty-minute trend-history state
- persistent shared header
- local display-controller backup-battery presentation

Page-specific layout and runtime remain in the corresponding `shared-*.yaml` composition packages.

---

## `display/shared-navigation.yaml`

Owns the six main navigation buttons shared by both V6 targets:

```text
Dashboard
Rectifiers
Battery
System
Cooling
Trends
```

Rectifier Detail remains a hierarchical child page and is not a seventh main-navigation item.

---

# Persistent Display Runtime

## `display/header.yaml`

Updates the persistent shared header independently of the active page.

Typical header information includes:

- date/time
- firmware identity
- charger run state
- local display-controller backup-battery indication

The Remote HMI adds its Home Assistant connectivity state through the target-specific `remote-hmi/connection-status.yaml` fragment.

---

## `display/command-state.yaml`

Owns asynchronous per-rectifier START/STOP transition display state.

Pending command state remains active even if the user leaves the page where the command originated.

This prevents command-completion handling from depending on one visible page.

---

## `display/local-battery-header.yaml`

Updates the local Waveshare display-controller backup-battery presentation shared by both targets.

Battery values change slowly and therefore use an independent low-rate refresh rather than being tied to faster page runtimes.

---

## `display/shared-dashboard.yaml`

Composes Dashboard-specific presentation and runtime consumed identically by both firmware targets.

Shared display infrastructure and persistent state are owned separately by `display/shared-hmi.yaml`. Target-specific state acquisition and command transport remain outside the Dashboard package behind the shared UI-model and `ui_command_*` interfaces.

---

## `display/shared-trends.yaml`

Composes the shared Trends page presentation and native chart runtime for both firmware targets.

Trend history and native chart build support remain owned by `display/shared-hmi.yaml` through `trend-state.yaml` and `chart-support.yaml`.

---

# Page-Specific Display Runtime

## `display/dashboard.yaml`

Updates Dashboard telemetry and charger-wide control presentation.

Runtime executes only while the Dashboard page is visible.

---

## `display/rectifiers.yaml`

Updates the three-unit Rectifiers overview.

Runtime includes:

- lifecycle state
- power state
- AC/DC summary telemetry
- button state
- unit availability

---

## `display/rectifier-detail.yaml`

Updates the shared Rectifier Detail page.

One page is reused for all three units.

The currently selected unit is stored in:

```text
rectifier_detail_unit
```

Runtime selects the corresponding telemetry dynamically.

---

## `display/battery.yaml`

Updates the four individual solar-battery cards.

Runtime executes only while the Battery page is visible.

The runtime consumes the centralized battery telemetry and availability state from `battery-bank.yaml` and renders:

- per-battery measurements
- warning and fault state
- consolidated battery status
- explicit missing-data presentation

It does not own battery acquisition or charger-control behavior.

---

## `display/cooling.yaml`

Updates the Cooling page.

The current page focuses on:

- shared compartment temperature
- shared compartment humidity
- internal Huawei rectifier-fan telemetry

External chassis-fan control is owned by `cooling.yaml`.

---

## `display/system.yaml`

Updates target-local diagnostics and shared rectifier status including:

- network information
- target runtime information
- memory information
- rectifier connectivity state

Local display-controller battery values are updated separately by `display/local-battery-header.yaml`.

---

## `display/trends.yaml`

Owns the shared native LVGL chart runtime.

Five independent 360-sample ring buffers are maintained locally on each V6 target by `display/trend-state.yaml`. They are sampled every ten seconds from the target-neutral shared UI model, providing sixty minutes of local history without Home Assistant history queries.

The display runtime:

- selects the active trend
- reads live values from the shared UI model
- combines DC current and DC voltage in one dual-axis chart
- calculates current/minimum/maximum values independently for both DC I/V series
- determines independent dynamic primary and secondary Y-axis ranges
- populates one or two LVGL series depending on the active trend
- renders unavailable samples as gaps

Native LVGL chart support is enabled by `display/chart-support.yaml`; the helper declarations remain in:

```text
../trend_helpers.h
```

---

# Static Display Pages

The files under:

```text
display/pages/
```

define LVGL layout only.

They SHOULD NOT own periodic telemetry-refresh logic.

Current pages:

```text
dashboard.yaml
rectifiers.yaml
rectifier-detail.yaml
battery.yaml
cooling.yaml
system.yaml
trends.yaml
```

The main navigation exposes:

```text
Dashboard
Rectifiers
Battery
System
Cooling
Trends
```

Rectifier Detail is a hierarchical child view rather than an additional main navigation page.

---

# Data and Control Paths

## Telemetry Path

The Charger Controller receives authoritative rectifier telemetry locally and publishes the HMI-facing state through the Controller UI backend:

```text
R4875G1
   │
   │ CAN
   ▼
rectifier-can/*.yaml
   │
   ▼
rectifier-unit.yaml sensors
   │
   ├── Home Assistant / MQTT / Web
   │
   ▼
controller/ui-backend.yaml
controller/ui-rectifier-backend.yaml
   │
   ▼
shared UI model
   │
   ▼
shared page runtimes
   │
   ▼
currently visible LVGL page
```

The Remote HMI receives the same authoritative charger state through Home Assistant and translates it into the same shared UI model:

```text
Charger Controller entities
   │
   │ Home Assistant
   ▼
remote-hmi/ha-backend.yaml
remote-hmi/rectifier-backend.yaml
   │
   ▼
shared UI model
   │
   ▼
shared page runtimes
   │
   ▼
currently visible LVGL page
```

Shared LVGL code therefore does not depend directly on CAN or raw Home Assistant transport entities.

---

## Charger Control Path

User intent follows approximately:

```text
controls.yaml
     │
     ▼
rectifier-shared.yaml
     │
     ├── hardware capability limit
     ├── thermal limit
     └── lifecycle / CAN eligibility
     │
     ▼
per-unit CAN command
     │
     ▼
R4875G1
```

This separation prevents UI entities from bypassing charger safety policy.

---

## Discovery Path

```text
OFFLINE unit
    │
    │ valid reconnect telemetry
    ▼
DISCOVERING
    │
    ▼
serialized discovery queue
    │
    ├── static properties
    ├── maximum-current capability
    └── address data
    │
    ▼
reapply active setpoints
    │
    ▼
ONLINE
```

Discovery is serialized because multi-frame property traffic temporarily requires coordinated access to the shared CAN bus.

---

## Display Update Path

```text
shared UI model
      │
      ▼
page-specific runtime
      │
      ▼
currently visible LVGL page
```

Persistent or target-local presentation uses separate runtimes:

```text
shared header
command transitions
local display-controller battery
local trend sampling
Remote HMI connection status
```

This architecture avoids continuously refreshing hidden pages while keeping persistent state independent of page visibility.

---

# Documentation Ownership

The documentation hierarchy is:

```text
../README.md
    project overview, hardware, operation and safety

README.md
    package ownership and implementation architecture

../R4875G1_CONTROL_FLOWS.md
    detailed lifecycle and control-flow behavior

../rules/
    repository development rules
```

Implementation-local details SHOULD remain close to the corresponding YAML rather than being duplicated here.

When package ownership or architecture changes, this document should be updated as part of the same functional change or immediately afterwards.

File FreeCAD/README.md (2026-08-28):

# R4875G1 Triple Rectifier Mount – FreeCAD

This directory contains the FreeCAD design for the mechanical mounting system of three Huawei R4875G1 rectifier modules used by the 3-phase charger project.

## Current Status

> **Work in Progress**

The design is still at an early stage.

The current model contains three main mounting parts:

* **Front holder**
* **Middle holder**
* **Back holder**

Together, these parts position and support three R4875G1 rectifiers mounted side by side.

The following parts are **not yet included** and are planned for future revisions:

* rear connection / wiring compartment
* mounting for cooling fans
* additional cable routing and mechanical details
* final mounting and enclosure details

Dimensions and geometry may therefore still change.

## Inspiration and Dimensions

The design was inspired by the excellent Huawei R48xx mechanical models from Patrick:

https://github.com/patagonaa/huawei-r48xx

In particular, this project uses the R48xx dimensions and mechanical geometry published there as an important reference for the rectifier fit and mounting concept.

The upstream project is licensed under the **MIT License**:

```text
Copyright (c) 2024 Patrick
```

Many thanks for publishing the original models and dimensional information.

## License

The FreeCAD models and mechanical designs in this directory are licensed under the **MIT License**, as part of the main repository.

See the repository's root `LICENSE` file for details.

Third-party source material remains subject to its respective upstream license.

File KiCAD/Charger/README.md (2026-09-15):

# R4875G1 3-Phase Charger – V4 KiCad Hardware

This directory contains the KiCad schematic and PCB design for the V4 hardware generation of the R4875G1 three-phase charger controller.

> [!IMPORTANT]
> This KiCad project does **not** represent the current V6 Charger Controller hardware.
>
> The current V6 firmware targets the Waveshare ESP32-S3-Touch-LCD-7 and uses a substantially different display, CAN, backup-encoder and external-I/O architecture.
>
> The V4 hardware remains a maintained hardware variant on the `v4-maintenance` branch.

## V4 Controller Hardware

The V4 controller is based on an **Espressif ESP32-S3-DevKitC-1** fitted with an **ESP32-S3-WROOM-1-N16R8** module with 16 MB Flash and 8 MB PSRAM.

The KiCad schematic uses the `PCM_Espressif:ESP32-S3-DevKitC` symbol and footprint.

The design includes the hardware required by the V4 controller architecture, including the external display, CAN interface, rotary encoder and chassis-fan connections.

## V4 GPIO Map

The KiCad design uses the following V4 controller assignments:

| Function | GPIOs |
|---|---:|
| Encoder push button | 2 |
| TFT backlight PWM | 4 |
| TFT CS / RESET / DC | 5, 6, 7 |
| I2C SDA / SCL | 8, 9 |
| TFT SPI MOSI / MISO / CLK | 11, 12, 13 |
| CAN / TWAI TX / RX | 15, 16 |
| Rotary encoder A / B | 17, 18 |
| FAN_ENABLE | 21 |
| FAN3_TACH / FAN2_TACH / FAN1_TACH | 39, 40, 41 |
| FAN_PWM | 42 |

These assignments describe the V4 KiCad hardware and MUST NOT be used as the GPIO map for the current V6 firmware.

## V6 Charger Controller Hardware

The current V6 Charger Controller uses the **Waveshare ESP32-S3-Touch-LCD-7** as its hardware platform.

Important architectural differences include:

| Function | V4 KiCad hardware | V6 Charger Controller |
|---|---|---|
| Controller | ESP32-S3-DevKitC-1 | Waveshare ESP32-S3-Touch-LCD-7 |
| Display | External ILI9488 over SPI | Onboard 800×480 RGB LCD |
| Touch | None | GT911 capacitive touch |
| CAN | External CAN interface | Onboard CAN transceiver |
| Rotary encoder | Direct GPIO17 / GPIO18, button GPIO2 | Direct GPIO11 / GPIO12, button GPIO13 |
| External fan enable | Direct ESP32 GPIO | MCP23017 GPA0 |
| Fan 1 / Fan 2 tachometer | Direct ESP32 GPIOs | MCP23017 GPA1 / GPA2 |
| MCP23017 interrupt | Not used | INTA / INTB intentionally unconnected |
| Fan 3 tachometer | Direct ESP32 GPIO | EMC2101 |
| External fan PWM | ESP32 PWM | EMC2101 |
| External I2C bus | Shared main bus | Dedicated GPIO44 / GPIO43 bus |

The V6 hardware architecture is documented in the repository root `README.md` and `packages/README.md`.

A V6 KiCad design should be maintained as a separate hardware design rather than modifying this V4 project in place.

## Project Files

```text
Charger.kicad_pro
    KiCad project configuration

Charger.kicad_sch
    main V4 controller schematic

fan-control.kicad_sch
    external fan-control schematic

Charger.kicad_pcb
    V4 PCB layout
```

## External Libraries

The project uses symbols, footprints and/or 3D models from the official Espressif KiCad Libraries:

`https://github.com/espressif/kicad-libraries`

The Espressif KiCad Libraries are licensed separately under the **Creative Commons CC BY-SA 4.0 License with the exception stated by Espressif**. See the upstream repository for the complete license terms.

## License

The charger PCB design and project files in this repository are licensed under the **MIT License**, unless otherwise noted.

Third-party library files remain subject to their respective upstream licenses.

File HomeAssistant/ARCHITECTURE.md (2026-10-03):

# Home Assistant Integration Architecture

## Status

Concept document only. No implementation code is defined by this document.

This document describes the intended long-term Home Assistant architecture for the R4875G1 three-phase charger project. It is deliberately separated from implementation so the integration boundary, data contract, frontend structure, distribution model and compatibility rules can be agreed before development starts.

## 1. Goal

The Home Assistant implementation should provide a charger dashboard that is visually and behaviorally close to the existing V6 touchscreen HMI while remaining a native Home Assistant extension.

The desired user experience is:

1. Install the R4875G1 Charger Home Assistant integration and dashboard frontend.
2. Add the integration through the Home Assistant UI.
3. Select one compatible Charger Controller instance.
4. Let the integration discover and validate the charger entities automatically.
5. Add an R4875G1 Charger dashboard.
6. The dashboard strategy automatically creates the complete charger dashboard for the selected charger instance.

The user should not need to configure individual sensor, number, button or binary-sensor entity IDs.

The implementation must support more than one charger instance. One configured Home Assistant integration entry represents one Charger Controller instance.

## 2. Architectural Position

The Home Assistant dashboard is an additional convenience HMI. It is not a replacement for the Charger Controller and it is not part of the charger safety or blackstart path.

The existing authority model remains unchanged:

```text
                         Charger Controller
                                |
             +------------------+------------------+
             |                  |                  |
             v                  v                  v
        Local LVGL HMI     Backup Encoder      Home Assistant
                                                     |
                                      +--------------+--------------+
                                      |                             |
                                      v                             v
                                 Remote HMI               HA Charger Dashboard
```

The Charger Controller remains authoritative for:

- CAN communication
- rectifier lifecycle
- capability detection
- thermal protection
- current limiting
- START eligibility
- charger START/STOP execution
- charger setpoints
- resulting charger state

The Home Assistant integration and dashboard must never reproduce these safety decisions.

A Home Assistant control action expresses operator intent and forwards that intent to the existing authoritative Charger Controller entities.

If Home Assistant, the frontend, the custom integration or the network is unavailable, the Charger Controller must continue operating independently.

## 3. Proposed Home Assistant Architecture

The Home Assistant solution consists of three coordinated layers:

```text
                    R4875G1 Home Assistant Solution
                                  |
             +--------------------+--------------------+
             |                    |                    |
             v                    v                    v
       Custom Integration   Dashboard Strategy    Custom Cards
          Python backend       dashboard factory    frontend UI
             |                    |                    |
             +--------------------+--------------------+
                                  |
                                  v
                        Charger Instance Model
                                  |
                                  v
                      Home Assistant registries
                                  |
                                  v
                  Existing ESPHome charger entities
```

### 3.1 Custom Integration

The custom integration is the backend adapter between a selected Charger Controller device and the frontend.

Its main responsibilities are:

- configuration through a Home Assistant config flow
- selection of one Charger Controller device
- validation that the selected device is a compatible charger
- discovery of the charger's entities
- mapping physical Home Assistant entities to stable semantic charger roles
- compatibility checking
- feature/capability reporting
- diagnostics
- providing the resolved charger-instance descriptor to the frontend
- reacting to entity-registry changes and entity renames
- supporting reconfiguration if the underlying Charger Controller device is replaced

The integration should not duplicate charger telemetry as a second set of Home Assistant entities unless a future requirement clearly justifies it.

The existing ESPHome entities remain the source of charger state.

### 3.2 Dashboard Strategy

The dashboard strategy creates the complete charger dashboard from one charger-instance reference.

The strategy should not contain installation-specific entity IDs.

Conceptually, its configuration contains only the selected R4875G1 Charger integration entry or charger-instance identifier.

The strategy generates the dashboard structure automatically and uses the custom frontend cards for the page content.

The strategy should register itself as a Home Assistant community dashboard so it can appear in the normal dashboard creation dialog on Home Assistant versions that support community dashboard registration.

### 3.3 Custom Cards

Custom cards render the actual charger UI.

The frontend should use reusable charger-specific web components rather than assembling the HMI from a large number of unrelated built-in Home Assistant cards.

This gives us control over:

- geometry
- typography
- state presentation
- dialogs
- status colors
- responsive behavior
- page navigation
- command-pending presentation
- invalid/unavailable states
- visual consistency with the physical HMI

The cards consume the semantic charger-instance descriptor rather than hard-coded entity IDs.

## 4. Recommended Dashboard Structure

The Home Assistant dashboard should preserve the functional structure of the V6 HMI:

```text
Dashboard
Rectifiers
Battery
System
Cooling
Trends
```

The Rectifiers page keeps the current hierarchical Rectifier Detail behavior.

### 4.1 Home Assistant Views

The preferred design is one Home Assistant view per main HMI page.

Each view is generated by the dashboard strategy and contains one full-width charger page card.

Example conceptual structure:

```text
HA Dashboard
|
+-- Dashboard view
|   `-- R4875G1 Dashboard page card
|
+-- Rectifiers view
|   `-- R4875G1 Rectifiers page card
|
+-- Battery view
|   `-- R4875G1 Battery page card
|
+-- System view
|   `-- R4875G1 System page card
|
+-- Cooling view
|   `-- R4875G1 Cooling page card
|
`-- Trends view
    `-- R4875G1 Trends page card
```

Using real Home Assistant views has several advantages over implementing the complete HMI as one opaque mini-application:

- every page has a stable URL
- browser back/forward navigation remains useful
- deep links are possible
- the dashboard remains recognizable as a Home Assistant dashboard
- page loading can remain modular
- individual page cards can also be reused elsewhere

The charger cards may still render the same persistent header and bottom navigation used by the physical HMI.

Navigation actions should change the Home Assistant view rather than maintaining an unrelated internal page router.

## 5. Frontend Component Model

The frontend should have a small number of public Home Assistant cards and a larger set of internal reusable components.

### 5.1 Public Cards

Initial public cards should correspond to complete HMI pages:

- Charger Dashboard
- Rectifiers
- Battery
- System
- Cooling
- Trends

A Rectifier Detail card may be public if useful, but the primary Rectifiers page can initially own the detail subview just as the physical HMI does.

### 5.2 Internal Components

Shared internal components should include concepts such as:

- charger page shell
- persistent header
- bottom navigation
- metric tile
- status badge
- overview card
- rectifier card
- battery card
- command button
- setpoint field
- modal dialog
- pending-command overlay
- unavailable-data state
- trend chart
- connection/status indicator

These components form a frontend design system for the charger.

The intent is not to share LVGL source code with Home Assistant. The two HMIs use different rendering technologies.

The shared asset is the information architecture and semantic UI model, not the rendering implementation.

## 6. Visual Design Strategy

The physical V6 HMI remains the visual reference.

The Home Assistant implementation should preserve:

- page hierarchy
- card grouping
- information density
- semantic colors
- status wording
- setpoint dialogs
- START/STOP dialogs
- rectifier detail organization
- major typography hierarchy
- the persistent header
- the six-page navigation model

The browser implementation should not attempt strict pixel-for-pixel rendering on every screen size.

Instead, it should define the physical 800 x 480 HMI as the reference layout and support responsive adaptations.

### 6.1 Reference Layout

The 800 x 480 display layout should be reproducible closely on a browser viewport with a similar aspect ratio.

This is important for:

- visual consistency
- documentation screenshots
- wall-mounted tablets
- side-by-side comparison with the physical HMI

### 6.2 Responsive Layout

The same frontend should also behave well on:

- desktop browsers
- tablets
- Home Assistant mobile applications
- narrow phone screens

Desktop and tablet layouts can preserve the multi-column HMI structure.

Narrow layouts may stack cards vertically while keeping the same semantic grouping.

### 6.3 Styling Boundary

The charger frontend should primarily use its own stable CSS component styles and charger-specific CSS variables.

Home Assistant theme variables may be consumed for basic integration with the surrounding application, but the implementation should avoid depending heavily on undocumented internal Home Assistant DOM structures or internal frontend components.

The charger UI should remain recognizable after normal Home Assistant frontend updates.

## 7. Charger Instance Model

The central architectural concept is the Charger Instance.

A Charger Instance is not another physical device. It is the integration's resolved semantic view of one existing Charger Controller device.

Conceptually it contains:

```text
Charger Instance
|
+-- identity
|   +-- integration entry
|   +-- Home Assistant device
|   +-- friendly name
|   +-- ESPHome identity
|   +-- firmware version
|   `-- charger interface/contract version
|
+-- compatibility
|   +-- compatible / degraded / incompatible
|   +-- missing required roles
|   `-- optional feature availability
|
+-- charger-wide telemetry
|
+-- charger-wide controls
|
+-- rectifier 1
|
+-- rectifier 2
|
+-- rectifier 3
|
+-- cooling
|
+-- system diagnostics
|
+-- optional external data sources
|   `-- battery bank
|
`-- frontend capabilities
```

The dashboard strategy and cards should reference the Charger Instance, not individual entity IDs.

## 8. Semantic Entity Contract

The custom integration needs a stable semantic contract between firmware and Home Assistant.

Examples of semantic roles are:

```text
charger.ac.power
charger.ac.voltage
charger.ac.current
charger.ac.current_limit

charger.dc.power
charger.dc.voltage
charger.dc.current
charger.dc.voltage_setpoint
charger.dc.sum_power_setpoint

charger.available_units
charger.running_units
charger.highest_output_temperature
charger.conversion_efficiency

charger.command.start
charger.command.stop

rectifier.1.lifecycle
rectifier.1.power_state
rectifier.1.can_connected
rectifier.1.ac.voltage
rectifier.1.dc.voltage
rectifier.1.temperature.output
rectifier.1.fan.rpm

cooling.compartment.temperature
cooling.compartment.humidity
cooling.fan.1.rpm
cooling.fan.2.rpm
cooling.fan.3.rpm

system.controller_battery.voltage
system.controller_battery.soc
```

The exact list should be defined later in a dedicated `ENTITY_CONTRACT.md`.

### 8.1 Why Semantic Roles Matter

The frontend should not know that a value currently happens to be represented by an entity named:

```text
sensor.some_prefix_combined_dc_power_all_units
```

It should request:

```text
charger.dc.power
```

The custom integration resolves that semantic role to the actual Home Assistant entity.

This isolates the frontend from:

- user-renamed entity IDs
- different charger device names
- installation-specific entity prefixes
- future entity naming cleanup
- multiple charger instances

## 9. Entity Discovery and Rename Safety

The config flow should ask the user to select a Charger Controller device, not an entity prefix.

The integration then inspects entities associated with that Home Assistant device.

The current Remote HMI prefix mapping is useful as a semantic inventory, but the new Home Assistant integration should not make the prefix the primary identity mechanism.

### 9.1 Initial Resolution

For the first implementation, entity discovery can use a combination of:

- selected Home Assistant device
- ESPHome integration ownership
- known domains
- known original entity names
- known stable unique identities
- expected charger entity combinations

The discovery process should reject ambiguous mappings rather than guessing silently.

### 9.2 After Initial Resolution

Once a role is resolved, the integration should track the entity through Home Assistant's entity registry rather than relying on the current editable entity ID.

If the user renames:

```text
sensor.charger_combined_dc_power_all_units
```

to:

```text
sensor.garage_charger_power
```

the Charger Instance should remain valid.

### 9.3 Recommended Future Firmware Anchor

A future small firmware enhancement should provide an explicit Home Assistant-facing charger interface identifier or contract version.

This could be a diagnostic entity or equivalent stable metadata that allows the integration to identify compatible Charger Controller devices without heuristics.

The interface version should describe the Home Assistant entity contract, not the complete firmware feature version.

Example concept:

```text
Firmware version:          6.2.0
HA charger contract:       1
```

A firmware update can then change from 6.2.0 to 6.3.0 without forcing a Home Assistant integration change if contract version 1 remains compatible.

## 10. Configuration Flow

The intended setup flow is:

```text
Settings
  -> Devices & services
  -> Add integration
  -> R4875G1 Charger
  -> Select Charger Controller
  -> Validate
  -> Create Charger Instance
```

### 10.1 Candidate Filtering

The device selector should preferably show only likely compatible Charger Controller devices.

Detection can use:

- ESPHome device ownership
- project metadata when available
- the future charger contract identifier
- presence of a minimum required entity set

### 10.2 Validation Result

The integration should classify the selected device as:

- Compatible
- Compatible with optional features missing
- Unsupported firmware/interface version
- Invalid Charger Controller selection

A missing safety-critical control mapping must not be silently substituted.

### 10.3 Reconfiguration

An options/reconfigure flow should support:

- replacing the underlying Charger Controller device
- re-running entity discovery
- resolving changed optional sources
- reviewing missing roles
- changing optional dashboard features

The generated dashboard should not need to be rebuilt manually after reconfiguration.

## 11. Multiple Charger Instances

Multiple chargers should be supported from the beginning.

Each config entry represents exactly one Charger Instance.

Example:

```text
R4875G1 Charger
|
+-- Garage Charger
|
`-- Workshop Charger
```

Each dashboard strategy instance references one Charger Instance.

This avoids a later architectural change if another charger is added.

## 12. Command Handling

The Home Assistant frontend must remain a command requester, not a charger controller.

### 12.1 Standard Command Path

The normal path is:

```text
Custom Card
   |
   v
Home Assistant action/service call
   |
   v
Existing ESPHome button/number entity
   |
   v
Charger Controller authoritative control path
   |
   v
CAN / safety / lifecycle logic
```

The custom integration may resolve which entity represents a semantic command, but it should not reproduce charger eligibility or safety rules.

### 12.2 No Optimistic Operational State

When the user requests START:

1. the UI may show that a request is pending
2. the UI sends the command through Home Assistant
3. the UI waits for authoritative Charger Controller state
4. only returned charger state determines whether the charger is shown as running

This mirrors the current Remote HMI authority model.

### 12.3 Connection Loss

If the Charger Controller entity set is unavailable:

- charger commands must be disabled
- unavailable state must be visible
- stale telemetry must not be rendered as healthy live data
- unavailable numeric values must not silently become zero

The Home Assistant dashboard is not an offline blackstart interface.

The direct Controller HMI and backup encoder retain that role.

## 13. Backend-to-Frontend Interface

The custom integration and frontend should communicate through a small explicit internal interface.

The frontend needs to obtain, at minimum:

- available Charger Instances
- selected instance identity
- display name
- compatibility state
- firmware version
- charger contract version
- semantic-role to entity mapping
- optional feature flags
- missing-role diagnostics

A small Home Assistant WebSocket API is the preferred conceptual boundary because it allows the frontend to request the resolved instance description without encoding integration internals into dashboard YAML.

The frontend should not read the integration's private Python storage directly.

The exact WebSocket commands and payload schema should be specified before implementation.

## 14. Required and Optional Capabilities

Not every future charger firmware version needs to expose exactly the same optional data.

The entity contract should classify roles.

### 14.1 Required Roles

Required roles are needed for a valid core Charger Instance.

Examples:

- charger availability
- main AC/DC telemetry
- active charger setpoints
- available/running unit counts
- charger START/STOP targets
- rectifier lifecycle and power state

If required roles are missing, setup should fail or the instance should be explicitly incompatible.

### 14.2 Optional Roles

Optional roles can enable or disable sections of the dashboard.

Examples may include:

- external cooling telemetry
- controller backup-battery monitoring
- detailed rectifier fan data
- extended diagnostics
- optional battery-bank context

The dashboard strategy can hide, disable or mark optional sections unavailable according to the capability descriptor.

## 15. Battery Page and External Home Assistant Data

The Battery page requires special treatment because the current physical HMI imports battery-bank data from other Home Assistant entities. Those source entities do not inherently belong to the Charger Controller device.

This creates an architectural difference between charger-native data and installation context.

### 15.1 Design Principle

The Home Assistant dashboard should read existing Home Assistant battery entities directly rather than routing those values through the Charger Controller merely to display them again in Home Assistant.

This avoids:

```text
Home Assistant battery source
        -> Charger Controller
        -> Home Assistant
        -> Charger dashboard
```

when the dashboard can instead use:

```text
Home Assistant battery source
        -> Charger dashboard
```

### 15.2 Desired User Experience

The long-term target remains one charger selection with automatic discovery whenever possible.

The integration should therefore support a secondary-source resolver that can:

1. discover known battery-bank source entities automatically when unambiguous
2. associate them with the Charger Instance
3. prompt only if discovery is ambiguous or incomplete

This keeps the common setup simple without hard-coding one installation's entity IDs into the frontend.

### 15.3 Fallback

If no battery source is configured or discoverable:

- the core charger dashboard remains valid
- the Battery page clearly reports that the optional source is not configured
- charger control remains unaffected

Battery source selection belongs to integration configuration, not individual dashboard-card configuration.

## 16. Cooling Page

Cooling data is charger-side data and should normally be discovered from the selected Charger Controller device.

The dashboard should preserve the distinction between:

- external chassis cooling
- internal rectifier fans

Cooling commands, if exposed, should use the same existing Home Assistant entities already owned by the Charger Controller.

The dashboard must not infer safety state from fan RPM alone.

## 17. System Page

The Home Assistant System page should distinguish two kinds of data:

### Charger Controller diagnostics

Examples:

- uptime
- Wi-Fi status
- ESPHome version
- controller battery
- local runtime information

### Charger operational state

Examples:

- rectifier lifecycle
- CAN connectivity
- charger firmware version
- integration/contract compatibility

The Home Assistant browser's own device diagnostics should not be confused with Charger Controller diagnostics.

## 18. Trends

The browser dashboard does not need to reproduce the Controller's in-memory 60-minute ring buffers internally.

Home Assistant already has persistent state history.

The preferred frontend approach is:

- request the required recent history/statistics from Home Assistant
- use the same five logical trend series as the physical HMI
- initially display the same 60-minute window
- preserve unavailable gaps rather than forcing zero
- use responsive browser-native chart rendering

This gives the Home Assistant dashboard an advantage over the physical HMI: trend data can survive frontend reloads and may later support selectable time ranges.

The visual default should still match the physical HMI closely.

## 19. Dialogs and Editing

Setpoint and power dialogs should visually follow the physical HMI.

The frontend should provide dedicated modal components for:

- AC current limit
- DC voltage and nominal sum power
- fallback voltage/current
- charger START
- charger STOP
- per-rectifier START/STOP
- rectifier detail commands where applicable

The modal owns presentation and input validation appropriate to the frontend.

The Charger Controller remains authoritative for operational acceptance.

The frontend should use the same configured ranges exposed by the entity where possible rather than duplicating numeric limits in JavaScript.

## 20. Availability Model

The Home Assistant frontend should have a consistent availability model.

Suggested instance states:

```text
OK
DEGRADED
OFFLINE
INCOMPATIBLE
```

### OK

All required roles are resolved and their current source data is available.

### DEGRADED

The core charger is usable but one or more optional capabilities are unavailable.

### OFFLINE

The Charger Controller is configured but authoritative entities are unavailable.

### INCOMPATIBLE

The selected device or firmware contract cannot satisfy the required semantic interface.

Cards should consume this instance-level state consistently instead of implementing independent ad-hoc availability rules.

## 21. Compatibility and Versioning

Three independent version concepts should exist.

### Firmware Version

Example:

```text
6.2.0
```

Owned by the charger firmware repository.

### Home Assistant Integration Version

Owned by the backend integration repository.

### Home Assistant Frontend Version

Owned by the dashboard/frontend repository.

### Charger Contract Version

Defines compatibility between firmware and the Home Assistant solution.

This contract should change only when the semantic Home Assistant interface changes incompatibly.

A compatibility matrix can then state, for example:

```text
HA contract 1
  compatible firmware: 6.2.x and later versions that retain contract 1
  backend integration: >= 1.x
  frontend: >= 1.x
```

The frontend should not compare firmware versions to guess entity availability when an explicit capability or contract version can answer the question.

## 22. Diagnostics

The custom integration should provide useful diagnostics without exposing secrets.

Diagnostics should include:

- configured Charger Instance
- selected Home Assistant device ID
- detected firmware version
- detected charger contract version
- resolved semantic roles
- missing required roles
- missing optional roles
- feature flags
- integration version
- compatibility result

The diagnostics should not include authentication credentials or unrelated Home Assistant state.

## 23. Testing Strategy

The Home Assistant solution needs its own validation layers.

### Backend Integration Tests

Cover:

- config flow
- candidate discovery
- duplicate prevention
- entity-role mapping
- renamed entity handling
- missing required entities
- optional entity handling
- reconfiguration
- compatibility checks

### Frontend Tests

Cover:

- semantic state rendering
- unavailable states
- dialog behavior
- responsive layout
- navigation
- command pending state
- multiple Charger Instances
- no accidental hard-coded installation entity IDs

### Integration Acceptance Tests

Cover at least:

- one complete Charger Controller
- renamed Home Assistant entities
- Charger Controller temporarily offline
- Home Assistant restart
- frontend/browser reload
- optional battery source missing
- optional battery source present
- multiple dashboard sessions
- multiple charger instances when available

No Home Assistant test replaces the existing physical firmware safety and blackstart validation.

## 24. Repository and Distribution Strategy

### 24.1 Recommendation

The Home Assistant architecture documentation should live in the existing charger repository because the entity contract and HMI semantics are part of the overall product architecture.

The production Home Assistant implementation should eventually be distributed from dedicated Home Assistant repositories.

This separation gives us both:

- one canonical project architecture
- clean Home Assistant/HACS packaging

### 24.2 Existing Charger Repository

Recommended structure:

```text
esphome-r4875g1-3phase-charger/
|
+-- HomeAssistant/
|   +-- ARCHITECTURE.md
|   +-- ENTITY_CONTRACT.md        future
|   +-- UI_SPEC.md                future
|   `-- TEST_PLAN.md              future
|
+-- packages/
+-- KiCAD/
+-- FreeCAD/
`-- ...
```

`HomeAssistant/ARCHITECTURE.md` is the conceptual document.

`ENTITY_CONTRACT.md` should become the authoritative semantic contract between ESPHome firmware and the Home Assistant integration.

`UI_SPEC.md` should describe page layouts, dialogs, visual semantics and responsive behavior without duplicating backend mapping details.

`TEST_PLAN.md` should define release acceptance for the Home Assistant solution.

No production Home Assistant runtime code needs to be added to this repository initially.

### 24.3 Backend Integration Repository

Recommended future repository:

```text
homeassistant-r4875g1-charger
```

Its purpose is the Home Assistant custom integration.

HACS-compatible integration repositories expect the integration below a root-level `custom_components/<domain>/` directory.

The backend repository should therefore be structured for Home Assistant rather than nested under the ESPHome firmware repository.

### 24.4 Frontend Repository

Recommended future repository:

```text
r4875g1-charger-dashboard
```

Its purpose is the dashboard strategy and custom cards.

HACS dashboard/plugin repositories have a different packaging model from custom integrations and normally publish JavaScript from a root-level or `dist/` location.

Keeping the frontend distribution separate avoids mixing two HACS repository types.

### 24.5 Why Not Put Production Code Under `HomeAssistant/` in the Existing Repository?

A nested `HomeAssistant/` source tree would be convenient for development, but it creates unnecessary distribution friction:

- HACS custom integrations expect a root-level `custom_components/<domain>/` structure
- HACS dashboard plugins expect their distributable JavaScript at the repository root or in `dist/`
- backend and frontend have different toolchains
- backend and frontend may need independent releases
- firmware releases should not automatically imply Home Assistant frontend releases
- Home Assistant code will eventually need its own tests and CI

Therefore:

```text
Existing repo
    owns architecture and firmware contract

Backend repo
    owns Home Assistant integration

Frontend repo
    owns dashboard strategy and custom cards
```

This is the preferred long-term structure.

A single-repository Home Assistant implementation can still be reconsidered later if distribution requirements change, but it should not be the baseline architecture.

## 25. Development Sequence

The recommended implementation order is deliberately contract-first.

### Phase 1 — Contract Definition

Create `ENTITY_CONTRACT.md`.

Define:

- required semantic roles
- optional semantic roles
- supported commands
- device identity/discovery anchor
- contract version
- availability semantics

No frontend work should begin before the core role names are stable.

### Phase 2 — Backend Integration Prototype

Create the Home Assistant custom integration.

Implement:

- config flow
- Charger Controller device selection
- entity discovery
- semantic mapping
- compatibility status
- frontend instance descriptor
- diagnostics

Do not create the full visual dashboard yet.

### Phase 3 — Frontend Design System

Create the frontend project.

Implement reusable visual components:

- shell
- header
- metric tiles
- status badges
- dialogs
- navigation
- unavailable state

Use static mock data only in isolated frontend development tests, never in production runtime.

### Phase 4 — Dashboard Page Cards

Implement the six page cards against the semantic instance descriptor.

Start with:

1. Dashboard
2. Rectifiers
3. System
4. Cooling
5. Battery
6. Trends

This order validates the most important charger-native data before optional external context and historical charting.

### Phase 5 — Dashboard Strategy

Generate the full dashboard automatically from one Charger Instance.

Add graphical strategy configuration and community-dashboard registration.

### Phase 6 — Secondary Source Discovery

Add battery-bank discovery/configuration.

Keep it optional and separate from the charger-native entity contract.

### Phase 7 — Distribution

Prepare:

- backend HACS integration repository
- frontend HACS dashboard repository
- release notes
- installation documentation
- compatibility matrix
- CI validation

## 26. Architectural Invariants

The following rules should be treated as non-negotiable unless the architecture is explicitly revised:

1. The Charger Controller remains authoritative for charger operation and safety.
2. Home Assistant must not become a dependency of local charger operation or blackstart.
3. The Home Assistant frontend must not implement independent START eligibility.
4. The dashboard must not hard-code one installation's entity prefix.
5. One Charger Instance must be configurable without manually entering every entity.
6. Entity renaming in Home Assistant should not break a configured Charger Instance.
7. Shared semantic roles are the boundary between backend discovery and frontend rendering.
8. Missing data must remain distinguishable from a valid zero value.
9. The Remote HMI and Home Assistant dashboard should share the same charger semantics even though their implementations are independent.
10. Optional external context such as the solar battery bank must not become a charger safety dependency.
11. Multiple charger instances must be possible without architectural redesign.
12. Firmware, backend, frontend and contract versions remain separate concepts.
13. Home Assistant frontend implementation must not depend unnecessarily on undocumented Home Assistant DOM internals.
14. The physical V6 HMI remains the visual and behavioral reference, but the browser implementation may adapt responsively.
15. Production Home Assistant backend and frontend distribution should remain independent from firmware release packaging.

## 27. Open Design Questions

The following questions should be resolved before implementation:

1. What exact firmware metadata or diagnostic entity should identify the charger contract version?
2. Which current ESPHome entities are mandatory for contract version 1?
3. Which current ESPHome entities are optional?
4. Should the integration resolve entities initially by original name, stable unique identity, or a dedicated future firmware key?
5. What is the exact backend-to-frontend WebSocket descriptor schema?
6. Should the dashboard allow hiding complete pages through integration options?
7. How should automatic battery-bank discovery work across installations?
8. Should the Home Assistant dashboard reproduce the physical HMI colors exactly or allow an optional Home Assistant theme-adaptive mode?
9. Should the Rectifier Detail screen remain an internal subview or become a dedicated Home Assistant view?
10. Which controls should be exposed on the Home Assistant System and Cooling pages?
11. How should pending command timeouts be presented if Home Assistant delivers the request but no authoritative state transition follows?
12. What minimum Home Assistant version should the first supported release require?

## 28. Current Recommendation

Proceed with the following repository decision now:

```text
Current charger repository
    HomeAssistant/ARCHITECTURE.md
```

Keep this document with the firmware because it defines how the Home Assistant product relates to the Charger Controller contract.

Do not add production Python or TypeScript/JavaScript implementation under `HomeAssistant/` yet.

Before creating implementation repositories, create `HomeAssistant/ENTITY_CONTRACT.md` and define contract version 1 from the current V6.2.0 Home Assistant-facing entities.

Once that contract is stable, create dedicated backend and frontend repositories with distribution-oriented layouts.

This gives the project a clean separation between:

```text
firmware authority
Home Assistant semantic contract
backend discovery/configuration
frontend presentation
distribution packaging
```

and preserves the same architectural discipline already used by the V6 Charger Controller and Remote HMI.

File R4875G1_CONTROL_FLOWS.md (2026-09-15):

# R4875G1 Three-Phase Charger — Control and Runtime Flows

This document describes the current V6 charger-control, CAN, lifecycle, safety and runtime architecture, including the coordinated Charger Controller and Remote HMI targets.

The firmware version is intentionally not duplicated here. `packages/version.yaml` is the single source of truth.

> **Scope:** behavioral firmware documentation, not an electrical safety specification.

## Runtime constants

| Function | Current value |
|---|---:|
| Project DC current ceiling | 75 A per rectifier |
| Capability fail-safe ceiling | 50 A per rectifier |
| Minimum DC current command | 1 A |
| DC voltage range / default | 49–58 V / 53 V |
| Overtemperature trip / reset | 90 °C / 80 °C |
| Raw CAN watchdog | 3 s ONLINE/OFFLINE; 7 s while DISCOVERING |
| Live telemetry freshness | 5 s |
| Fast polling cycle | 577 ms |
| Offline probe slot / per-unit maximum | 5 s / ≈15 s |
| TWAI recovery check | 2 s |
| Active-setpoint refresh | 30 s |
| Reconnect stabilization | 5 s |
| Property bus quiet period | 500 ms |
| Property / capability attempts | 3 / 10 |
| TWAI RX queue | 64 frames |
| Display resolution | 800×480 landscape |
| LVGL framebuffer | 100%, 16-bit RGB565 |
| Controller battery display refresh | 5 s |

# 1. System architecture

```mermaid
flowchart LR
    AC[Three-phase AC source] --> U1[R4875G1 Unit 1]
    AC --> U2[R4875G1 Unit 2]
    AC --> U3[R4875G1 Unit 3]

    U1 --> DCBUS[Common DC bus / battery]
    U2 --> DCBUS
    U3 --> DCBUS

    CTRL[Waveshare ESP32-S3-Touch-LCD-7] <--> CAN[125 kbit/s extended CAN]
    CAN <--> U1
    CAN <--> U2
    CAN <--> U3

    CTRL --> LCD[7-inch 800×480 RGB LCD]
    TOUCH[GT911 touchscreen] --> CTRL

    ENC[Direct backup rotary encoder] --> CTRL
    CTRL <--> EXT_I2C[External I2C bus]
    EXT_I2C --> MCP[MCP23017]
    EXT_I2C --> EMC[EMC2101]
    EXT_I2C --> BME[BME280]

    EMC --> FANS[External chassis fans]
    MCP --> FANS

    CTRL <--> HA[Home Assistant]
    RHMI[Remote HMI] <--> HA
    CTRL <--> MQTT[MQTT]
```

Core charging remains local. Wi-Fi, Home Assistant, MQTT and Internet access are optional for charger control and blackstart.

# 2. Firmware module ownership

The V6 firmware keeps Charger Controller authority, Remote HMI transport, target-neutral UI state and shared LVGL presentation behind explicit ownership boundaries:

| Source | Primary responsibility |
|---|---|
| `r4875g1-3phase-charger.yaml` | Charger Controller composition, substitutions, unit instances, identity, boot sequence and aggregate entities |
| `r4875g1-remote-hmi.yaml` | Remote HMI composition and installation-specific Home Assistant pairing |
| `packages/shared/core.yaml` | target-neutral ESP32-S3 platform, Wi-Fi, API, web, OTA and time services |
| `packages/shared/hardware.yaml` | target-neutral Waveshare onboard I2C, CH422G, touch and local backup-battery hardware |
| `packages/shared/local-diagnostics.yaml` | target-local ESP32, network and runtime diagnostics shared by both V6 targets |
| `packages/shared/ui-model.yaml` | target-neutral charger state consumed by shared HMI code |
| `packages/shared/battery-monitoring.yaml` | shared Home Assistant solar-battery monitoring composition and UI backends |
| `packages/controller/hardware.yaml` | Charger Controller external I2C, MCP23017 fan I/O, direct backup encoder and CAN |
| `packages/controller/encoder.yaml` | network-independent backup encoder setpoint and charger power control state machine |
| `packages/controller/encoder-ui.yaml` | Controller-only LVGL feedback for backup encoder interaction |
| `packages/controller/environment.yaml` | rear-compartment BME280 temperature, humidity and pressure |
| `packages/controller/mqtt.yaml` | Charger Controller MQTT command and state transport |
| `packages/controller/ui-backend.yaml` | authoritative local Controller state mapped into the shared UI model |
| `packages/controller/ui-commands.yaml` | shared UI command intents executed through authoritative local Controller controls |
| `packages/remote-hmi/ha-backend.yaml` | authoritative Charger Controller state imported through Home Assistant |
| `packages/remote-hmi/rectifier-backend.yaml` | per-unit authoritative rectifier state imported through Home Assistant |
| `packages/remote-hmi/ui-commands.yaml` | shared HMI command intents transported through Home Assistant |
| `packages/controls.yaml` | charger-wide controls and setpoints |
| `packages/cooling.yaml` | external chassis-fan control, EMC2101 telemetry, PWM management and RPM monitoring |
| `packages/rectifier-unit.yaml` | parameterized per-unit state, telemetry and discovery |
| `packages/rectifier-shared.yaml` | cross-unit lifecycle, limits, CAN scheduling, recovery and control |
| `packages/rectifier-can/*.yaml` | parameterized CAN receive handlers |
| `packages/display/shared-*.yaml` | shared V6 HMI composition used by both targets |
| `packages/display/pages/*.yaml` | static shared LVGL page layouts |
| `packages/display/{header,command-state,dashboard,rectifiers,rectifier-detail,battery,cooling,system,trends}.yaml` | persistent and page-specific shared display runtimes |

# 3. Rectifier lifecycle

```mermaid
stateDiagram-v2
    [*] --> OFFLINE: ESP boot
    OFFLINE --> DISCOVERING: valid CAN heartbeat
    DISCOVERING --> ONLINE: discovery verified + restore complete
    DISCOVERING --> OFFLINE: discovery failed
    ONLINE --> OFFLINE: CAN lost outside discovery/grace
    ONLINE --> DISCOVERING: manual/full discovery
```

`OFFLINE` units receive no normal fast polling or START. `DISCOVERING` proves hardware identity/capability/address. `ONLINE` is the operationally released state.

# 4. Boot sequence

```mermaid
flowchart TD
    A[ESP boot] --> B[Restore persistent user setpoints]
    B --> C[Power states UNKNOWN]
    C --> D[Effective current limit = 50 A fail-safe]
    D --> E[Lifecycle 1..3 = OFFLINE]
    E --> F[Initialize controller hardware and display]
    F --> G[Start periodic CAN and lifecycle runtime]
    G --> H[Normal runtime]
```

Initial current command scaling is `1024 / 75`. Capability discovery later recomputes shared scaling.

# 5. CAN transport strategy

**Single-Shot is used only for slow OFFLINE reconnect probes.** Normal telemetry, fan polling, property/capability discovery, active setpoints, reconnect restore, ON/OFF and broadcast configuration use normal ESPHome CAN transmission. TWAI BUS_OFF recovery remains the final controller-level recovery layer.

# 6. Normal fast polling

Every 577 ms, while property discovery is not owning the bus, each lifecycle-`ONLINE` rectifier is queried for cyclic telemetry and then fan telemetry. Units 2 and 3 follow the configured inter-unit gaps. `OFFLINE` and `DISCOVERING` units are excluded.

# 7. Raw CAN watchdog

Valid per-unit traffic refreshes `last_can_rx_x`. Communication is fresh for 3 seconds during normal operation and for 7 seconds while the unit is DISCOVERING, so the intentional 5-second stabilization window cannot expire the watchdog. Loss changes `CAN Communication Unit x` to false, invalidates that unit's capability contribution and eventually demotes lifecycle `ONLINE → OFFLINE`; its published power state becomes `UNKNOWN`.

# 8. Slow OFFLINE probing and reconnect

One unit slot is considered every 5 seconds in round-robin order. Only an `OFFLINE` unit receives a Single-Shot cyclic probe, so a continuously offline unit is probed about every 15 seconds.

A returned heartbeat changes `OFFLINE → DISCOVERING`, clears the previous capability-valid state and starts a 5-second stabilization period before serialized discovery.

# 9. Discovery

Discovery runs one rectifier at a time:

```mermaid
flowchart TD
    A[Queue unit] --> B[Static properties]
    B --> C[Capability + address]
    C --> D{CAN fresh + required data complete?}
    D -- No --> E[OFFLINE]
    D -- Yes --> F[Targeted active setpoint restore]
    F --> G[ONLINE]
```

Static property discovery has a 500 ms quiet period and up to 3 attempts. Capability/address discovery has up to 10 attempts. The tested property response contained 56 frames; the TWAI RX queue is 64 frames.

# 10. Effective DC current limit

Only currently CAN-reachable units participate:

```text
no reachable units                       -> 50 A
any reachable capability still unknown  -> 50 A
all reachable capabilities known         -> min(75 A, reachable capabilities)
```

A disconnected unit is removed immediately. A reconnecting unit forces the fail-safe until its capability is freshly rediscovered.

# 11. Current command scaling

The current implementation has **no permanent Unit-1 scaling dependency**:

```text
unknown/incomplete reachable capabilities:
    current_scaling_factor = 1024 / 75

all reachable capabilities known:
    current_scaling_factor = 1024 / highest reachable capability
```

The effective engineering-current ceiling independently uses the **lowest** reachable capability. This combination is deliberately conservative for differing reachable capabilities.

Raw command selection is bounded in protocol space:

```text
requested_raw      = round(requested_A × scaling)
hardware_limit_raw = floor(effective_limit_A × scaling)
thermal_limit_raw  = floor(thermal_limit_A × scaling)
raw_command        = min(requested_raw, hardware_limit_raw, thermal_limit_raw)
```

# 12. Capability mismatch

`Rectifier Capability Mismatch` considers currently reachable units only:

```text
UNKNOWN = fewer than two reachable units or a reachable capability is unknown
OFF     = reachable capabilities match within 0.25 A
ON      = at least two reachable capabilities differ by >0.25 A
```

The diagnostic itself does not inhibit charging; fail-safe current limiting/scaling handles the operational boundary.

# 13. Active setpoints and reconnect restore

Normal active voltage/current changes and the 30-second refresh are sent only to `ONLINE` + CAN-fresh rectifiers. A rediscovered unit receives its current active voltage and current through targeted unit-specific CAN commands before returning to `ONLINE`. Restore does not send ON.

Fallback voltage/current remain broadcast configuration commands.

# 14. Nominal power target

```text
I_each = P_target / (3 × V_DC)
```

The divisor intentionally remains fixed at three. Therefore, before losses/clamping, two active rectifiers deliver roughly 67% and one roughly 33% of the configured nominal three-unit target. The firmware does not automatically increase remaining-unit current when a rectifier disappears.

# 15. Blackstart and local control

Blackstart is implemented independently from Home Assistant, MQTT, Wi-Fi and Internet connectivity.

START evaluates each rectifier independently. A unit must be `ONLINE`, CAN-fresh, explicitly `OFF`, have valid output-temperature telemetry below 90 °C and have no overtemperature lockout. Active setpoints are refreshed before individual ON commands are issued.

STOP remains unrestricted.

The V6 Charger Controller provides touchscreen-based local control through the shared LVGL interface and a separate backup rotary-encoder path for blackstart use.

The encoder is connected directly to the ESP32-S3:

```text
GPIO11 -> Encoder S1 / A
GPIO12 -> Encoder S2 / B
GPIO13 -> Encoder KEY
```

The encoder uses a staged local editor:

```text
short press 1 -> edit DC voltage
rotation      -> adjust voltage in 0.1 V steps
short press 2 -> edit nominal DC sum power
rotation      -> adjust power in 0.1 kW steps
short press 3 -> apply both pending setpoints
15 s idle     -> discard pending edits
```

A long press while the editor is idle requests charger START or STOP. START/STOP and saved setpoints are forwarded through the existing authoritative Charger Controller `ui_command_*` paths, so lifecycle, CAN freshness, thermal protection and START eligibility are not duplicated in the encoder implementation.

The LVGL encoder overlay is feedback-only. Touchscreen input, Home Assistant, MQTT and Internet connectivity are not dependencies of the backup encoder control state machine.

# 16. Thermal derating

The most severe per-unit thermal state determines a shared thermal current ceiling:

| State | Enter | Recovery threshold | Shared limit |
|---|---:|---:|---:|
| `NORMAL` | <70 °C | — | 75 A |
| `WARNING_1` | ≥70 °C | <65 °C | 50 A |
| `WARNING_2` | ≥80 °C | <75 °C | 30 A |
| `LOCKOUT` | ≥90 °C | <80 °C | 30 A + individual OFF |

Applied current is `min(requested, hardware capability limit, thermal limit)`. Derating never overwrites the user's requested current. Stale temperature cannot relax a warning or lockout, and lockout recovery never automatically starts a rectifier.

# 17. Telemetry and aggregate sensors

Cyclic selectors include operating hours (`0x0E`), AC power (`0x70`), frequency (`0x71`), AC current (`0x72`), DC power (`0x73`), DC voltage (`0x75`), configured max DC current (`0x76`), AC voltage (`0x78`), output temperature (`0x7F`), input temperature (`0x80`) and DC current (`0x81`). Most engineering values use `raw / 1024`.

Aggregate AC/DC power, average AC voltage, average AC phase current, DC current, average DC voltage, highest output temperature and efficiency include only CAN-fresh units with valid required telemetry. `Available Units` returns the CAN-reachable rectifier count. `Running Units` returns the number of CAN-reachable rectifiers explicitly reporting their power state as `ON`.

Solar-battery telemetry is imported independently from Home Assistant through `packages/shared/battery-monitoring.yaml`, which composes the source mappings and aggregate/per-unit UI backends. Aggregate bank data and four per-battery data sets are used exclusively for display monitoring. Home Assistant battery availability does not participate in rectifier lifecycle, current limiting, START eligibility or CAN control.

# 18. V6 shared LVGL display behavior

Both V6 targets use the Waveshare ESP32-S3-Touch-LCD-7 with a 7-inch 800×480 RGB display and GT911 capacitive touchscreen. Shared LVGL presentation consumes the target-neutral UI model; the Charger Controller publishes local authoritative state while the Remote HMI imports authoritative state through Home Assistant.

LVGL tracks touchscreen inactivity. After the configured display idle timeout, the firmware pauses LVGL rendering and disables the CH422G-controlled display backlight while non-display runtime continues normally. A touchscreen release wakes the display without activating the control underneath the wake-up touch.

The shared LVGL interface exposes six primary navigation pages:

```text
Dashboard
Rectifiers
Battery
System
Cooling
Trends
```

The Rectifiers page additionally opens one shared hierarchical Rectifier Detail view for Unit 1, Unit 2 or Unit 3.

The current shared display composition is:

```text
display/shared-hmi.yaml
    shared display hardware, theme, UI state, trend history and persistent header

display/shared-dashboard.yaml
display/shared-rectifiers.yaml
display/shared-battery.yaml
display/shared-cooling.yaml
display/shared-system.yaml
display/shared-trends.yaml
    shared page-specific presentation and runtime

display/shared-navigation.yaml
    shared six-page bottom navigation

display/pages/*.yaml
    static shared LVGL page layouts
```

Normal page telemetry is refreshed only while the corresponding page is visible. Persistent header state, command transitions, local backup-battery presentation and trend sampling continue independently.

The Charger Controller additionally composes `controller/encoder-ui.yaml` for local backup-encoder feedback. The Remote HMI does not include charger-side encoder hardware or duplicate charger safety logic.

The display layer does not own charger safety policy. Lifecycle, CAN freshness, thermal protection, command acceptance and START eligibility remain authoritative on the Charger Controller.

# 19. TWAI BUS_OFF recovery

Every 2 seconds the controller checks TWAI state. `BUS_OFF` initiates recovery; `STOPPED` restarts TWAI. This is a final recovery mechanism, not the normal rectifier reconnect path.

# 20. Verified physical reconnect behavior

The 2026-08-27 physical test remains the validated CAN baseline: unplugging CAN while the rectifier stayed powered caused the 3-second watchdog to expire, lifecycle moved to OFFLINE, slow Single-Shot probes continued, reconnect triggered DISCOVERING, the 56-frame property exchange and capability/address discovery completed, active setpoints were restored, and lifecycle returned to ONLINE without an ESP reboot.

The tested reduced-current connector configuration reported a 52 A capability. That trace remains valid protocol evidence because the current V6 HMI and hardware composition does not change the validated rectifier CAN protocol and lifecycle model.

# 21. Safety and behavioral invariants

1. Every rectifier boots `OFFLINE`.
2. Raw CAN reachability is not operational readiness.
3. Only `ONLINE` units receive normal fast polling.
4. Only `ONLINE` + CAN-fresh units receive normal active setpoints.
5. `OFFLINE` units are probed sparsely with Single-Shot.
6. Discovery must verify before `ONLINE` promotion.
7. START requires lifecycle, CAN, power-state and temperature safety checks.
8. STOP is unrestricted.
9. Nominal power always divides by three.
10. Effective current ceiling uses the lowest known reachable capability with a 50 A fail-safe for incomplete discovery.
11. Shared command scaling uses the highest reachable capability once all reachable capabilities are known.
12. Thermal/hardware limits clamp applied current without overwriting requested current.
13. Property discovery is serialized.
14. BUS_OFF recovery is a final recovery layer.
15. LVGL affects presentation only; charger control and safety decisions remain outside the shared display layer.
16. Backup encoder setpoint and START/STOP requests reuse authoritative Charger Controller command paths and do not duplicate CAN or safety policy.
17. Remote HMI commands remain requests transported through Home Assistant; the Charger Controller remains authoritative for acceptance, execution and resulting state.
18. Home Assistant solar-battery telemetry is monitoring-only and cannot affect charger control or safety behavior.

## Source status

This document describes the current V6 implementation from:

```text
r4875g1-3phase-charger.yaml
r4875g1-remote-hmi.yaml
packages/
trend_helpers.h
```

The firmware version is defined only in `packages/version.yaml`.

The physical CAN disconnect/reconnect test from 2026-08-27 remains the validated protocol and lifecycle baseline for reconnect behavior. Current V6 hardware and HMI documentation reflects the coordinated Charger Controller and Remote HMI architecture.

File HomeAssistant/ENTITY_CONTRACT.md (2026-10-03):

# Home Assistant Charger Entity Contract

## Status

Draft contract for the first Home Assistant integration generation.

This document defines the semantic interface between the R4875G1 Charger Controller firmware and the planned Home Assistant custom integration/dashboard.

It does not define Python or frontend implementation details beyond what is required to keep the interface stable.

The current V6.2.0 firmware is used as the source inventory for Contract 1.

Contract 1 should be considered formally implemented only after the Charger Controller firmware exposes an explicit Home Assistant contract identifier as described in this document.

## 1. Purpose

The Home Assistant custom integration must be able to identify one compatible Charger Controller and resolve its Home Assistant entities without requiring the user to enter individual entity IDs.

The frontend must consume stable semantic roles rather than installation-specific Home Assistant entity IDs.

Conceptually:

```text
Home Assistant entity
        |
        v
Custom Integration
        |
        | resolves
        v
Semantic Role
        |
        v
Dashboard / Custom Card
```

Example:

```text
sensor.hg_dg_technik_charger_combined_dc_power_all_units

                    becomes

charger.dc.power
```

The semantic role is stable even if the Home Assistant entity ID is renamed by the user.

## 2. Contract Principles

The following principles are normative for Contract 1.

1. The Charger Controller remains authoritative for charger operation and safety.
2. The Home Assistant integration does not implement CAN logic, START eligibility, lifecycle decisions, thermal protection or capability limiting.
3. The Home Assistant integration should not create duplicate telemetry entities merely to rename existing ESPHome entities.
4. The frontend consumes semantic roles, not hard-coded entity IDs.
5. Entity renames in Home Assistant must not invalidate an already configured Charger Instance.
6. Missing data must remain distinguishable from a valid zero value.
7. One integration config entry represents exactly one Charger Controller instance.
8. Multiple Charger Controller instances must be supported.
9. Optional installation context such as the solar battery bank is outside the core charger contract.
10. The current Remote HMI entity-prefix map is an inventory/reference, not the long-term Home Assistant discovery mechanism.
11. The Home Assistant solution must not become a dependency of local charger operation or blackstart.
12. Contract compatibility is independent from the normal firmware version.

## 3. Contract Identity

### 3.1 Firmware Project Identity

The current Charger Controller firmware declares:

```text
ESPHome project name:
anwa.r4875-charger
```

The Remote HMI uses a different project identity:

```text
anwa.r4875-remote-hmi
```

The Home Assistant integration must only create a Charger Instance for the Charger Controller.

ESPHome project metadata should be used as one discovery signal where Home Assistant exposes it reliably.

### 3.2 Contract Version

A dedicated contract version must be added to the Charger Controller firmware before Contract 1 is considered production-ready.

Recommended semantic value:

```text
1
```

Recommended Home Assistant-facing entity:

```text
Name:
R4875G1 Charger Contract

Semantic role:
metadata.contract_version

Expected state:
1
```

This entity should be diagnostic and read-only.

The exact ESPHome implementation belongs to a later firmware change.
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

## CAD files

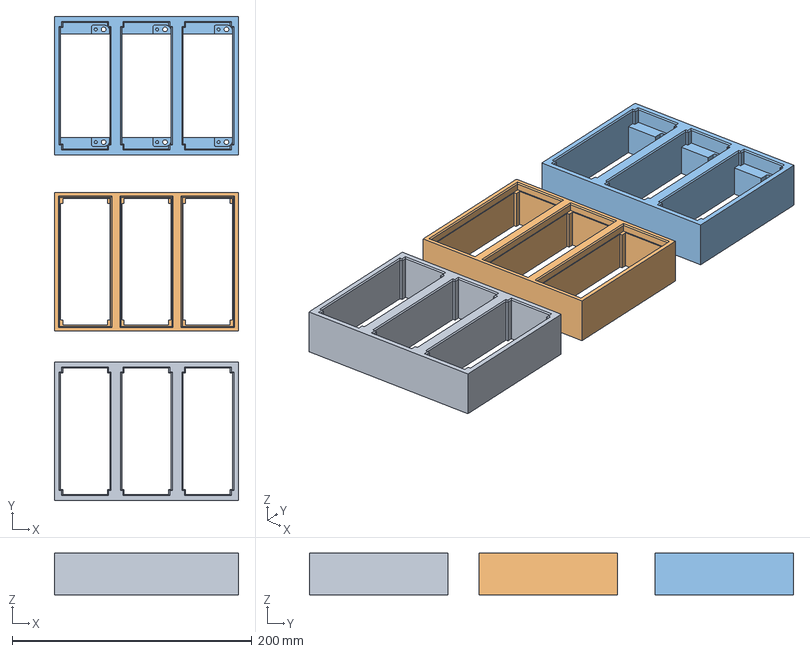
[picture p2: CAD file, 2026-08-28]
FreeCAD/3xR48xx_Gehäuse.FCStd
153.6 x 403.5 x 35.0 mm
Middle
Front
Back

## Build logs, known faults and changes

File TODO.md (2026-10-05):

# Project TODO

This file tracks current unfinished work for the primary V6 charger generation. It is a working backlog, not a changelog. Completed items should be removed or reflected in the appropriate permanent documentation rather than retained as development history.

## Priority Legend

- **P0** — blocker or reliability issue that should be understood before dependent work continues
- **P1** — next functional or correctness work
- **P2** — planned improvement or design decision
- **P3** — deferred, external-dependency or long-term work

## P1 — Backup Blackstart Acceptance Validation

The backup rotary encoder now uses direct ESP32-S3 GPIOs and reuses the authoritative Charger Controller command paths. Before treating the next V6 milestone as a release checkpoint, validate the intended degraded-operation behavior explicitly.

- [ ] Verify DC-voltage and nominal DC sum-power editing with Wi-Fi, Home Assistant and MQTT unavailable.
- [ ] Verify long-press charger START/STOP with network services unavailable.
- [ ] Verify that touchscreen interaction is not required for the encoder state machine or command path.
- [ ] Verify that the 15-second edit timeout discards pending values without changing active setpoints.

## P2 — MCP23017 Fan Tachometer Margin Validation

The MCP23017 is now reserved for external cooling-fan power and Fan 1 / Fan 2 tachometer inputs on GPA0–GPA2. INTA and INTB are intentionally unconnected.

- [ ] Verify Cooling Fan 1 and Cooling Fan 2 tachometer readings at the maximum expected fan speed.
- [ ] Perform sustained high-speed fan runtime testing to confirm the non-interrupt MCP23017 input path has sufficient pulse-capture margin.

## P1 — Optional Motion-Wake Fallback Validation

Motion-based display wake is intentionally optional per target. Both current targets use a Home Assistant motion source, so the no-motion configuration still needs an explicit validation pass.

- [ ] Build a V6 target with the `display_motion` package omitted.
- [ ] Verify that the original LVGL idle-timeout behavior remains active without a motion source.
- [ ] Verify that touching a sleeping display still wakes it without activating the control underneath the wake-up touch.
- [ ] Confirm that no dummy Home Assistant entity or target-specific workaround is required when motion wake is disabled.

## P2 — Final Per-Target Motion Sensor Configuration

The two current V6 targets temporarily use the same Home Assistant occupancy entity. The architecture already supports independent target-specific entity IDs.

- [ ] Assign the final Charger Controller motion/occupancy entity when its installation location is finalized.
- [ ] Assign the final Remote HMI motion/occupancy entity when its installation location is finalized.
- [ ] Tune `display_idle_timeout` independently for each target based on the actual sensor hold time and desired user experience.

## P2 — Reduced-Rectifier Power-Target Strategy

The nominal DC sum-power calculation intentionally divides the configured target by three. If one or two rectifiers are unavailable, the remaining units do not automatically increase current to compensate.

- [ ] Decide whether the fixed three-unit divisor should remain the permanent safety/behavior policy.
- [ ] If power redistribution is desired, define the behavior explicitly for three, two and one available rectifier before changing the implementation.
- [ ] Ensure any redistribution remains bounded by per-unit hardware capability, effective current limit, thermal derating and AC-side constraints.
- [ ] Avoid automatic current jumps that could surprise the operator when rectifier availability changes.
- [ ] Update `R4875G1_CONTROL_FLOWS.md` together with any functional change to this policy.

## P2 — Mechanical Design Completion

The current FreeCAD model provides the front, middle and back holders but the complete charger enclosure is still work in progress.

- [ ] Add the rear connection / wiring compartment.
- [ ] Add mounting for the cooling fans.
- [ ] Add final cable-routing features.
- [ ] Complete final mounting and enclosure details.
- [ ] Re-check clearances and service access after the electrical layout is finalized.

## P3 — ESP32-S3 Flash / PSRAM Performance

The Waveshare platform is currently kept at the supported 80 MHz Flash / 80 MHz Octal PSRAM configuration. The documented 120 MHz option should remain deferred until ESPHome and ESP-IDF support it cleanly.

- [ ] Re-evaluate 120 MHz Flash / Octal PSRAM when stable ESPHome support becomes available.
- [ ] Do not enable unsupported or experimental production overrides merely to reach 120 MHz.
- [ ] Benchmark LVGL responsiveness, free heap, largest free heap block and runtime stability before and after any future change.

## P3 — Home Assistant Deployment Transport

The deployment script already retries file transfers, but intermittent SSH deployment timeouts have previously occurred outside the script's control.

- [ ] Reproduce the intermittent Home Assistant SSH deployment timeout if it still occurs.
- [ ] Identify the root cause instead of relying only on retry behavior.
- [ ] Keep deployment retries as resilience, not as a substitute for resolving a reproducible transport problem.

## P3 — Installed-System Rectifier Telemetry Validation

Several rectifier telemetry functions cannot be meaningfully or safely validated in the laboratory because the lab setup has no battery or suitable DC load. These checks are intentionally deferred until the charger is installed in the island system or another appropriate load is available.

- [ ] Validate register `0x0174` reported efficiency under real DC load.
- [ ] Compare `0x0174` reported efficiency against the calculated `DC Power / AC Power` efficiency at several stable load levels.
- [ ] Check reported efficiency behavior at low, medium and high charger output power.
- [ ] Observe additional `0x0183` alarm/status bits during normal operation where they occur naturally.
- [ ] Do not intentionally provoke potentially destructive `0x0183` fault conditions solely to verify undocumented R4875G1 behavior.
- [ ] Record any R4875G1-specific deviations from the Huawei reference bit mapping if they are observed.

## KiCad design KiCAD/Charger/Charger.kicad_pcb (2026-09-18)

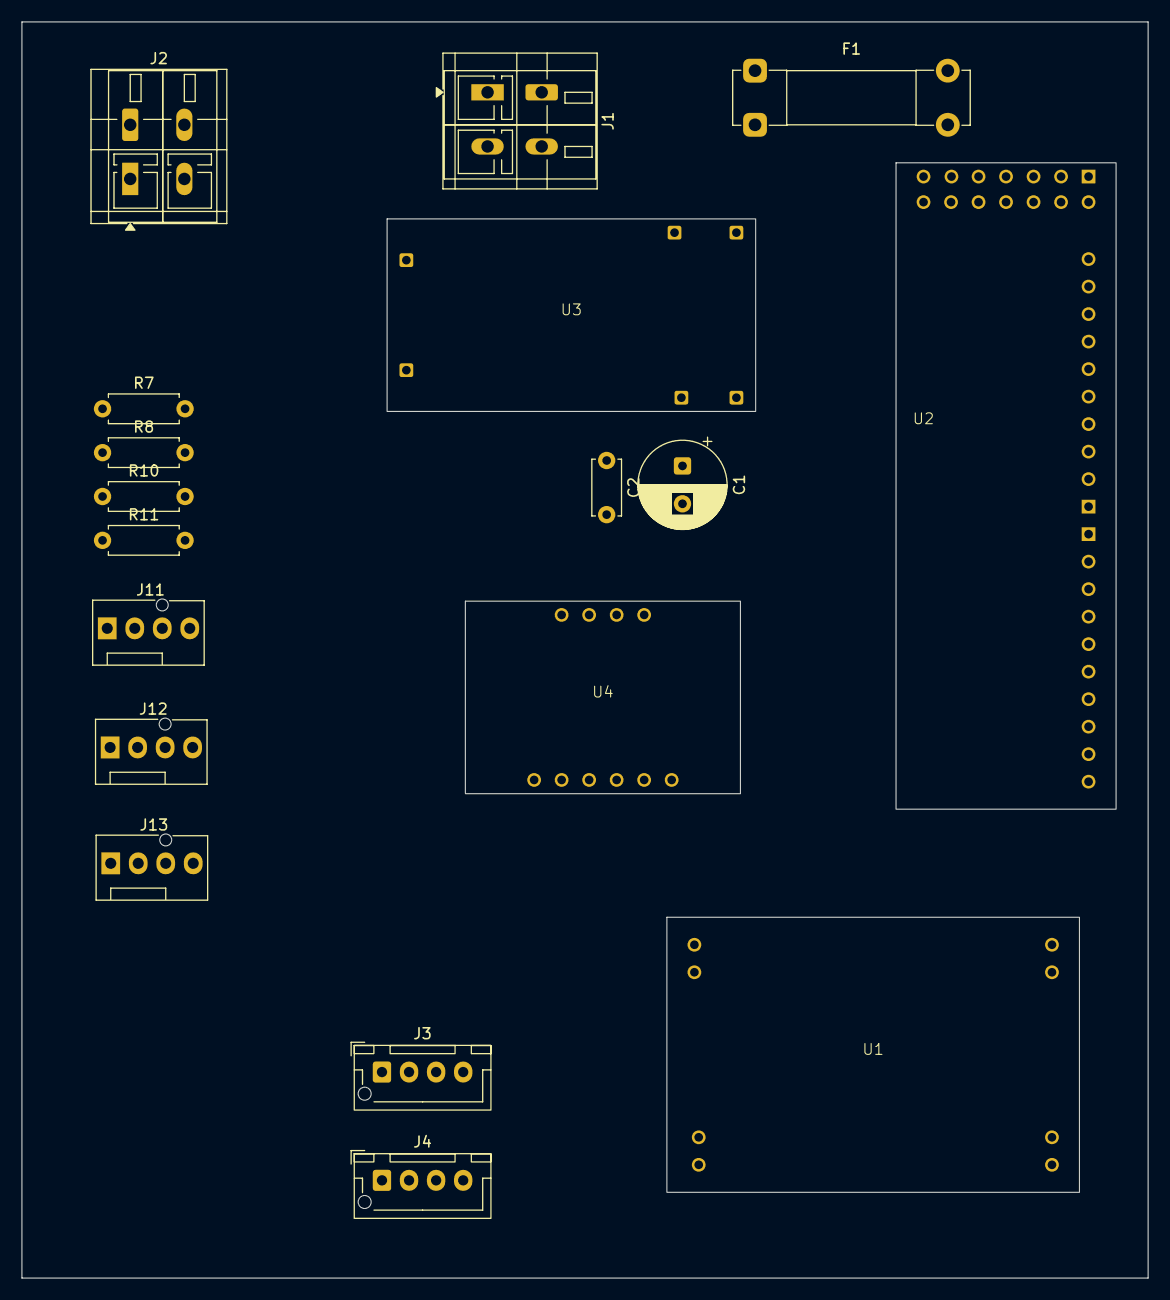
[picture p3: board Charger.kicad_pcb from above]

Board: 2 copper layers, 104.0 x 116.0 mm, 18 parts (0 on the bottom side), 13 nets, no tracks yet.

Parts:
C1: 470uF; CP_Radial_D8.0mm_P3.50mm
C2: 100nF; C_Disc_D5.0mm_W2.5mm_P5.00mm
F1: Fuse_Small; Fuseholder_Clip-5x20mm_Bel_FC-203-22_Lateral_P17.80x5.00mm_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
J1, J2: Screw_Terminal_01x02; TerminalBlock_WAGO_236-402_1x02_P5.00mm_45Degree
J3, J4: Conn_01x04_Socket; JST_XH_B4B-XH-AM_1x04_P2.50mm_Vertical
J11, J12, J13: Conn_01x04; FanPinHeader_1x04_P2.54mm_Vertical
R7, R8: 10k; R_Axial_DIN0207_L6.3mm_D2.5mm_P7.62mm_Horizontal
R10, R11: 1k; R_Axial_DIN0207_L6.3mm_D2.5mm_P7.62mm_Horizontal
U1: DC-DC
U2: MCP23017
U3: MOSFET
U4: EMC2101

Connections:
+3.3V: J3.2, J4.2, R7.1, R8.1, U2.1 (VCC), U2.18 (VCC), U4.1 (VIN)
+12V: C1.1, C2.1, F1.2, U1.2 (IN+)
/FAN1_TACH: R10.1, U2.21 (PA1)
/FAN2_TACH: R11.1, U2.22 (PA2)
/FAN+: J11.2, J12.2, J13.2
/PWM: J11.4, J12.4, J13.4, U4.8 (FAN)
/SCl: J3.3, J4.3, U4.5 (SDA)
/SDA: J3.4, J4.4, U2.4 (SDA), U4.4 (SCL)
/TACH1: J11.3, R7.2, R10.2, U4.7 (TACH)
/TACH2: J12.3, R8.2, R11.2
GND: C1.2, C2.2, J1.2, J2.2, J3.1, J4.1, J11.1, J12.1, J13.1, U1.1 (IN-), U1.3 (OUT-), U2.2 (GND), U2.19 (GND), U3.2 (GND_2), U4.3 (GND)
unnamed: F1.1, J1.1
unnamed: J2.1, U1.4 (OUT+)

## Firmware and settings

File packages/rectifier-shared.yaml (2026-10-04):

# ==============================================================================
# SHARED RECTIFIER CONTROL PACKAGE
# ==============================================================================
#
# Provides charger-wide rectifier state, lifecycle coordination, safety limits,
# setpoint handling, CAN frame routing, discovery scheduling and periodic
# communication tasks shared by all three R4875G1 units.
# ==============================================================================

globals:
  # ---------------------------------------------------------------------------
  # COMMUNICATION SCHEDULER STATE
  # ---------------------------------------------------------------------------

  # Timestamp when static-property discovery most recently ended.
  # Used for the post-discovery grace period before connectivity demotion
  # resumes.
  - id: last_property_discovery_end
    type: uint32_t
    restore_value: false
    initial_value: "0"

  # Next unit considered by the round-robin OFFLINE probe scheduler.
  - id: offline_probe_next_unit
    type: uint8_t
    restore_value: false
    initial_value: "1"

  # ---------------------------------------------------------------------------
  # THERMAL DERATING STATE
  # ---------------------------------------------------------------------------
  #
  # Updated only from valid output-temperature telemetry. A stale/NAN value
  # never relaxes an existing warning or lockout.
  # ---------------------------------------------------------------------------

  - id: thermal_dc_current_limit
    type: float
    restore_value: false
    initial_value: "${project_max_dc_current_a}f"

  # ---------------------------------------------------------------------------
  # CURRENT LIMIT AND PROTOCOL SCALING
  # ---------------------------------------------------------------------------

  # Shared current-command scaling factor.
  #
  # Before all currently reachable rectifiers have fresh capability data, use
  # the 75 A command scale (1024 / 75). This is the conservative universal
  # command fallback: lower-current 50/52 A units are under-driven rather than
  # over-driven while their exact capability is unknown.
  #
  # Once every currently CAN-reachable unit has a fresh capability, the scale
  # is derived from the highest capability among those reachable units. The
  # shared effective current ceiling is independently derived from the lowest
  # capability, so mixed-capability installations remain fail-safe.
  - id: current_scaling_factor
    type: float
    initial_value: "static_cast<float>(${protocol_value_scale}) / ${project_max_dc_current_a}f"
    restore_value: false

  # Effective maximum DC current command used by all current-control paths.
  #
  # Start conservatively at 50 A. Only units with fresh CAN communication are
  # considered. The limit may rise above 50 A only after every currently
  # reachable unit has a freshly confirmed capability; it then becomes the
  # lowest capability among those reachable units, capped by the 75 A project
  # maximum. A reachable unit with unknown capability immediately forces the
  # limit back to 50 A.
  - id: effective_dc_current_limit
    type: float
    initial_value: "${failsafe_dc_current_a}f"
    restore_value: false

  # Fixed-point protocol scale used by voltage and most telemetry fields.
  # This is a protocol constant and must always start from protocol_value_scale;
  # it is therefore never restored from persistent storage.
  - id: voltage_scaling_factor
    type: int
    initial_value: "${protocol_value_scale}"
    restore_value: false
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

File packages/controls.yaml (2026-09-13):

# ==============================================================================
# CHARGER CONTROLS PACKAGE
# ==============================================================================
#
# Charger-wide setpoints and shared control entities.
#
# This package contains controls that affect the complete three-rectifier
# charger. Per-unit controls are instantiated separately from
# rectifier-unit.yaml.
#
# CAN command encoding remains centralized here or in the shared control
# scripts referenced by these entities.
# ==============================================================================

number:

  # ---------------------------------------------------------------------------
  # INTERNAL RECTIFIER FAN MINIMUM DUTY
  # ---------------------------------------------------------------------------
  #
  # Broadcasts the minimum duty for the rectifiers' built-in fans using Huawei
  # CAN command selector 0x14. This is not the external chassis-fan PWM.
  # ---------------------------------------------------------------------------

  - platform: template
    name: "Set Fan Minimum Speed"
    id: set_fan_min_speed
    min_value: 0
    max_value: 100
    step: 1
    unit_of_measurement: "%"
    optimistic: true
    mode: SLIDER
    restore_value: true
    initial_value: 0
    icon: "mdi:fan"
    on_value:
      then:
        # Allow the optimistic number entity to finish updating before reading
        # its new state and constructing the CAN command.
        - delay: 0.01s
        - lambda: |-
            // Log the requested engineering value before CAN encoding.
            float fan_value = id(set_fan_min_speed).state;
            ESP_LOGI(
              "custom",
              "Received fan minimum speed: %.0f%%",
              fan_value
            );
        - canbus.send:
            use_extended_id: true
            can_id: 0x108080FE
            data: !lambda |-
              // Build an 8-byte broadcast command frame initialized to zero.
              std::vector<uint8_t> can_data(8, 0x00);
              // Command group 0x01 with selector 0x14 addresses the
              // minimum fan duty-cycle setting.
              can_data[0] = 0x01;
              can_data[1] = 0x14;
              // Convert percentage to the rectifier fixed-point format.
              // Example:
              //   25% * 256 = 6400 = 0x1900
              const int scaled_value =
                  static_cast<int>(
                    id(set_fan_min_speed).state *
                    ${fan_duty_counts_per_percent}f
                  );
              // Store the 16-bit value in big-endian format.
              can_data[2] = (scaled_value >> 8) & 0xFF;
              can_data[3] = scaled_value & 0xFF;
              // Bytes 4..7 remain zero.
              return can_data;

  # ---------------------------------------------------------------------------
  # DC VOLTAGE LIMIT
  # ---------------------------------------------------------------------------
  #
  # Primary charger-wide DC voltage setpoint.
  #
  # The requested engineering value uses 0.1 V resolution and is converted to
  # the Huawei fixed-point CAN representation before being applied to all
  # eligible ONLINE rectifiers.
  # ---------------------------------------------------------------------------

  - platform: template
    name: "Set DC Voltage Limit"
    id: set_dc_voltage_limit
    min_value: ${dc_voltage_min_v}
    max_value: ${dc_voltage_max_v}
    step: 0.1
    unit_of_measurement: "V"
    icon: "mdi:flash"
    optimistic: true
    mode: BOX
    restore_value: true
    initial_value: ${dc_voltage_default_v}
    command_topic: "${mqtt_command_prefix}/set_dc_voltage"
    on_value:
      then:
        - lambda: |-
            // Encode engineering volts into the rectifier's fixed-point CAN format.
            float voltage_value = id(set_dc_voltage_limit).state;
            ESP_LOGI(
              "custom",
              "Received DC voltage limit: %.1f V",
              voltage_value
            );

        - script.execute: send_active_voltage_to_online_units

  # ---------------------------------------------------------------------------
  # DC CURRENT LIMIT
  # ---------------------------------------------------------------------------
  #
  # Charger-wide per-unit current request.
  #
  # The requested current is constrained by detected hardware capability and
  # thermal derating before the active command is sent to the rectifiers.
  # ---------------------------------------------------------------------------
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

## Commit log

2026-08-17 Improve ESP32-S3 board configuration and fix CAN board 3 handling
    * Optimize ESP32-S3 N16R8 configuration for 16 MB flash and 8 MB Octal PSRAM
    * Enable WiFi PSRAM usage and disable WiFi power saving for improved stability
    * Move I2C SDA away from GPIO8 to avoid conflict with the onboard WS2812 LED
    * Optimize ILI9488 display rotation using hardware transform
    * Move sensitive API and fallback AP credentials to secrets
    * Fix Board 3 property parsing incorrectly referencing Board 2 data
    * Correct Board 3 property logging
    * Fix incorrect Board 2 label in Board 3 maximum-current logging
    [r4875g1-3phase-charger.yaml]
2026-08-17 Fix printf format specifiers for temperature values
    * Add missing float conversion specifiers to temperature placeholders
    * Resolve compiler warnings about unknown conversion characters
    * Fix extra printf argument warnings in display output
    [r4875g1-3phase-charger.yaml]
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2026-08-17 Improve local blackstart sequencing and offline charger operation
    * Disable WiFi, API, and MQTT reboot timeouts for reliable offline operation
    * Limit local DC sum power setpoint to 11 kW to stay within 75 A per rectifier
    * Add dedicated blackstart start and stop scripts
    * Ensure voltage and calculated current setpoints are sent before enabling the rectifiers
    * Add controlled delays to guarantee deterministic CAN command sequencing
    * Use actual rectifier power states for local start/stop decisions
    * Remove dependency on the local charger state flag
    [r4875g1-3phase-charger.yaml]
2026-08-17 Improve local blackstart display and encoder feedback
    * Replace temporary setpoint display values with live charger setpoints
    * Show DC voltage, total DC power, and calculated current per rectifier
    * Highlight the currently selected encoder parameter in bold blue
    * Display actual rectifier ON/OFF status including partial 1/3 and 2/3 states
    * Update the display immediately on encoder rotation
    * Refresh the display immediately when switching between voltage and power selection
    [r4875g1-3phase-charger.yaml]
2026-08-17 Improve encoder responsiveness and local input handling
    * Increase display refresh rate to 500 ms
    * Remove forced display updates on every encoder step to prevent queued refreshes and input lag
    * Increase DC sum power setpoint limit to 12 kW
    * Simplify button debounce handling with a 30 ms delayed on/off filter
    * Extend short-press detection window to improve rotary encoder button reliability
    [r4875g1-3phase-charger.yaml]
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2026-08-17 Use live charger telemetry in display and expand font glyph support
    * Replace temporary AC input values with live grid voltage, input current, and frequency sensors
    * Replace temporary DC values with live voltage, current, and power sensors for all three rectifiers
    * Standardize Google Fonts configuration using explicit family definitions
    * Add `<` and `>` glyphs to all configured fonts
    * Resolve missing glyph warnings for encoder selection indicators
    [r4875g1-3phase-charger.yaml]
2026-08-17 Add per-module CAN communication monitoring and display fault handling
    * Add CAN communication health monitoring for all three charger modules
    * Track the last valid cyclic CAN data frame received from each module
    * Expose `can_com_ok_1` to `can_com_ok_3` as diagnostic connectivity sensors
    * Mark module communication as failed after a 3-second CAN timeout
    * Replace stale or invalid module values on the display with a clear CAN communication fault message
    * Highlight CAN communication faults in bold red text
    [r4875g1-3phase-charger.yaml]
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2026-08-17 Improve AC display handling for partial CAN communication failures
    * Use only modules with valid CAN communication for AC display values
    * Calculate average AC voltage, current, and frequency from reachable modules
    * Sum AC power only from modules with valid telemetry
    * Show the number of active modules contributing to the displayed values
    * Add NaN checks to avoid incomplete startup data on the display
    * Show a clear CAN communication fault message when no charger module is reachable
    [r4875g1-3phase-charger.yaml]
2026-08-17 Make combined AC and DC power sensors CAN-aware
    * Exclude modules with failed CAN communication from combined power calculations
    * Ignore invalid NaN power values from individual charger modules
    * Sum only currently reachable modules for AC and DC power totals
    * Return unavailable instead of 0 kW when no valid module data is available
    * Prevent stale power values from disconnected modules affecting Home Assistant and energy calculations
    [r4875g1-3phase-charger.yaml]
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2026-08-18 Refactor charger setpoint naming and scaling terminology
    * Rename voltage and current setpoint entities for clearer DC charger semantics
    * Rename the current scaling factor to `current_scaling_factor` across CAN decoding, display, scripts, and telemetry filters
    * Replace legacy `can_voltage_set` and `can_amp_set` identifiers with `set_dc_voltage_limit` and `set_dc_current_limit`
    * Rename fallback voltage and current entities for consistent naming
    * Update rotary encoder, blackstart, periodic CAN refresh, and MQTT paths to use the new setpoint IDs
    * Reorganize voltage and current number definitions for improved readability
    * Add clearer logging for voltage and current setpoint updates
    * Remov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
    [r4875g1-3phase-charger.yaml]
2026-08-18 Add configurable minimum fan speed control
    - Add a persistent fan minimum speed setpoint from 0 to 100 percent
    - Broadcast the fan duty-cycle setting to all rectifier modules over CAN
    - Encode fan speed using the rectifier fixed-point format with a factor of 256
    - Add logging for fan minimum speed changes
    - Expose the setting as a slider in ESPHome and Home Assistant
    - Document the CAN command format and fan speed scaling
    [r4875g1-3phase-charger.yaml]
2026-08-18 fix: add hysteresis and lockout to overtemperature shutdown
    Context:
    - Output temperature on_value handlers for Module 1-3 previously
    re-sent the CAN OFF command on every 3s telemetry update whenever
    the temperature was above 90°C, with no protection against an
    operator immediately turning an overheated module back on via the
    "ON Module-X" buttons or the blackstart start sequence.
    Changes:
    - Added three new globals (overtemp_lockout_1/2/3) tracking the
    overtemperature state per module.
    - Output Temperature Module-1/2/3 sensors now trip the lockout once
    (edge-triggered) when exceeding 90°C, sending CAN OFF only on that
    transition, and clear the lockout only once the temperatu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
    [r4875g1-3phase-charger.yaml]
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2026-08-18 fix: rename module-1 scaling factor sensor and align accuracy decimals
    - The "Scaling Factor Module-1" template sensor was renamed from
    sf_value to sf_value_1, and two new placeholder sensors
    (Scaling Factor Module-2/3, sf_value_2/sf_value_3) were added for
    future per-module scaling factor diagnostics.
    - Accuracy of most current/power/voltage/frequency template sensors
    was increased from 1-2 to 3 decimal places for finer-grained
    telemetry display and logging.
    - Renamed id sf_value -> sf_value_1 on the "Scaling Factor Module-1"
    sensor and added "Scaling Factor Module-2" (sf_value_2) and
    "Scaling Factor Module-3" (sf_value_3) template sensors.
    - Updated accurac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
    [r4875g1-3phase-charger.yaml]
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2026-08-18 fix: keep current_scaling_factor derivation exclusive to Module 1
    - Renaming amp_scaling_factor to current_scaling_factor also
    changed the Module 2 and Module 3 max-current CAN handlers to
    write into the same shared current_scaling_factor global,
    instead of only publishing their own diagnostic value. This
    contradicted the documented architecture ("derived from Module 1")
    and made the shared current-command scaling depend on whichever
    module's capability frame was processed last.
    - Added FAN RPM Module-1/2/3 and Info: Operating Hours Module-1/2/3
    sensors were missing their usual section header comments, and the
    operating-hours sensors used state_class: measurement ins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
    [r4875g1-3phase-charger.yaml]
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2026-08-18 Migrate ILI9488 display to mipi_spi with correct landscape orientation
    * Replace the deprecated ili9xxx display driver with mipi_spi
    * Keep 8-bit color depth and full framebuffer operation
    * Preserve the 40 MHz SPI data rate for responsive display updates
    * Configure explicit 480x320 landscape dimensions
    * Apply the correct axis transform for the ILI9488 panel orientation
    * Remove the inverted display orientation while preserving the existing UI layout
    [r4875g1-3phase-charger.yaml]
2026-08-19 Code-Review
    * Fix 3. "Input Grid Voltage Module-1" weiterhin mit 10 s statt 3 s
    * Fix 7. Unicode-Sonderzeichen ⁄ in Name/SSID
    * Fix 10. Neu: Namensinkonsistenz bei `fallback_amp_set`
    [r4875g1-3phase-charger.yaml]
2026-08-19 Code-Review
    * Fix comiler warning abaout friendly name and GPIO
    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
    [r4875g1-3phase-charger.yaml]
2026-08-19 Fix some Problems
    * friendly name contains '/' which is reserved as a URL path separator
    * GPIO19 is used by the USB-Serial-JTAG interface. Using this pin as GPIO will conflict with USB-Serial-JTAG.
    [r4875g1-3phase-charger.yaml]
2026-08-19 Fix Problems from code review
    * 1. current_scaling_factor-Vergleich weiterhin praktisch wirkungslos
    * 5. Neue Sensoren weiterhin ohne `device_class`/`state_class`
    * 7. Neu: Unerreichbare `== 0`-Zweige in der Strom-Validierung
    * 10. Neu: `Fallback Voltage Set` folgt nicht dem neuen Namensschema
    [r4875g1-3phase-charger.yaml]
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2026-08-19 Fix Problems from code review
    * 9. Neu: Deutscher Kommentar mitten im englischen Kommentarstil
    * Fix LOG messages for DC current setpoints
    [r4875g1-3phase-charger.yaml]
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2026-08-20 Minor
    * add missing id for setup button
    * changed logging to reduce canbus messages
    * update code review
    [r4875g1-3phase-charger.yaml]
2026-08-20 Code Review
    * Fixed 8. CAN RX jetzt auf GPIO16 – Kollision mit (deaktiviertem) Touchscreen-Kommentar
    [r4875g1-3phase-charger.yaml]
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2026-08-22 Fix capability discovery fail-safe handling
    * Fix unreachable fail-safe checks after the 10-attempt discovery loops
    * Determine discovery success from the actual capability and address flags
    * Avoid false failure warnings when data arrives on the final attempt
    * Add explicit success logging with the number of attempts used
    * Improve failure logs to identify whether current capability or address data is missing
    [r4875g1-3phase-charger.yaml]
2026-08-22 Harden CAN frame parsing against invalid payload lengths
    * Validate capability response frames before accessing fixed byte positions
    * Validate shelf and slot address frames before decoding Pin 11 and Pin 12
    * Reject malformed or truncated CAN frames with diagnostic warnings
    * Remove unnecessary fixed-size memcpy operations from CAN handlers
    * Decode required payload bytes directly from the received CAN frame
    * Improve CAN parser robustness without changing normal protocol behavior
    [r4875g1-3phase-charger.yaml]
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2026-08-22 Make rectifier power states CAN-aware
    - Set per-unit power state to UNKNOWN when CAN communication times out
    - Initialize all rectifier power states as UNKNOWN during controller boot
    - Restore ON, OFF, or ERROR from the next valid rectifier status frame
    - Remove redundant cached power-state values from CAN handlers
    - Count units as running only when their CAN communication is valid
    - Prevent stale ON states from affecting local charger state detection
    - Inhibit local START when no rectifier is reachable over CAN
    - Update README with CAN-aware power-state and blackstart safety behavior
    [r4875g1-3phase-charger.yaml]
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2026-08-22 Invalidate stale CAN telemetry sensor values
    - Add 5-second freshness timeouts to per-unit live CAN telemetry sensors
    - Mark stale voltage, current, power, frequency and temperature values unavailable
    - Add timeout handling to rectifier fan RPM telemetry
    - Add timeout handling to reported DC current setpoints
    - Publish alternate DC current on every valid CAN status frame
    - Remove change-only caching that prevented reliable alternate-current timeout detection
    - Preserve static discovery, capability and lifetime counter values across CAN outages
    - Keep combined AC/DC power handling unchanged because it is already CAN-aware
    - Update README with live telemetry freshness and retention behavior
    [r4875g1-3phase-charger.yaml]
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2026-08-22 Make overtemperature protection edge-triggered
    - Send the per-unit CAN OFF command only when entering an overtemperature condition
    - Engage the overtemperature lockout before transmitting the shutdown command
    - Prevent repeated OFF frames while temperature remains above 90 °C
    - Preserve the 90 °C trip and 80 °C recovery hysteresis
    - Ignore NaN temperature updates without changing lockout state
    - Keep an active lockout latched across temporary CAN telemetry loss
    - Use consistent hexadecimal formatting for rectifier OFF commands
    - Expand README documentation for overtemperature trip, lockout and recovery behavior
    [r4875g1-3phase-charger.yaml]
2026-08-22 Require valid temperature telemetry before rectifier startup
    - Require fresh CAN communication before issuing per-unit ON commands
    - Require a valid output-temperature value before allowing startup
    - Block startup when output temperature exceeds the 90 °C trip threshold
    - Preserve overtemperature lockout checks for the full hysteresis behavior
    - Make blackstart startup fail-safe immediately after ESP32 reboot
    - Prevent stale temperature telemetry from allowing a rectifier to restart
    - Apply the same safety checks to individual Home Assistant and web ON controls
    - Require all three units to pass safety checks before broadcast ON
    - Keep OFF commands unrestricted so shutdown is always availabl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
    [r4875g1-3phase-charger.yaml]
2026-08-22 Fix rectifier capability handler mapping
    - Remove the duplicated legacy Unit 1 capability handler
    - Restore the correct capability CAN ID for Unit 2
    - Add the missing Unit 3 capability handler
    - Validate capability frame length before accessing payload bytes
    - Decode maximum current directly from validated CAN frames
    - Keep Unit 1 as the canonical source for the shared current scaling factor
    - Preserve Unit 2 and Unit 3 scaling values as diagnostics
    [r4875g1-3phase-charger.yaml]
2026-08-22 Initialize and refresh current scaling factor safely
    - Replace the generic 15.0 current scaling default with the R4875G1 75 A value
    - Use 1024 / 75 as the immediate model-specific fallback after boot
    - Stop restoring the hardware-derived scaling factor from persistent storage
    - Automatically refresh Unit 1 capability data when CAN communication becomes available
    - Recalculate the shared current scaling factor from the detected Unit 1 maximum current
    - Preserve Unit 1 as the canonical scaling source for the three-rectifier charger
    - Keep Unit 2 and Unit 3 scaling values diagnostic-only
    - Preserve immediate offline blackstart capability before discovery completes
    - Update architecture comments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
    [r4875g1-3phase-charger.yaml]
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2026-08-22 Add rectifier capability mismatch diagnostics
    - Compare maximum-current capabilities reported by all three rectifiers
    - Add a Home Assistant diagnostic problem entity for capability mismatches
    - Keep the diagnostic unknown until all three capability values are confirmed
    - Invalidate capability consistency whenever a new discovery cycle starts
    - Trigger comparison automatically when fresh capability data is published
    - Use a 0.25 A tolerance for the protocol's 0.5 A capability resolution
    - Log matching capability values at INFO level
    - Log mismatched rectifier capabilities as an explicit error
    - Leave charger start be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
    [r4875g1-3phase-charger.yaml]
2026-08-22 Centralize effective DC current limiting
    - Add one shared effective DC current limit for all charger current-control paths
    - Start with the 75 A R4875G1 project ceiling
    - Reduce the effective limit to the lowest valid detected rectifier capability
    - Add a diagnostic sensor exposing the active effective current limit
    - Recalculate the limit whenever fresh rectifier capability data is received
    - Immediately reduce active and fallback current setpoints when a lower capability is detected
    - Replace scaling-factor-based 75/50/30 A current-limit heuristics
    - Use the effective limit for normal DC current, fallback current and total-power conversion
    - Preserve the static 75 A Number range as the abs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
    [r4875g1-3phase-charger.yaml]
2026-08-22 Clarify three-unit DC power target behavior
    - Define DC Sum Power Set as a nominal three-rectifier power target
    - Keep the power-to-current calculation intentionally fixed at three units
    - Avoid automatic current redistribution during partial-unit operation
    - Clarify that one or two active rectifiers produce proportionally less total power
    - Update local display labels to distinguish the three-unit target from measured DC output
    - Improve current-calculation logs with explicit three-unit target terminology
    - Document the safety rationale for not compensating automatically after CAN loss
    - Clarify partial-unit behavior in the README
    [r4875g1-3phase-charger.yaml]
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2026-08-22 Standardize visible entity naming
    - Use Unit 1, Unit 2 and Unit 3 consistently without hyphens
    - Use All Units consistently for broadcast and combined entities
    - Rename combined power entities to reference All Units
    - Standardize all configurable values with Set-prefixed names
    - Rename DC Sum Power Set to Set DC Sum Power
    - Replace symbolic ON and OFF button names with clear action labels
    - Standardize per-unit and all-unit fan control button names
    - Remove redundant Button suffixes from button entity names
    - Rename SETUP to Discover Rectifier Units
    - Normalize Fan capitalization across telemetry entities
    - Keep internal ESPHome IDs unchanged for a separate refactoring step
    - Update README r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
    [r4875g1-3phase-charger.yaml]
2026-08-22 Clarify remaining internal entity IDs
    - Rename scaling factor sensor IDs to descriptive per-unit names
    - Rename dc_sum_power_set to set_dc_sum_power
    - Update all internal references to the renamed entities
    - Align internal setpoint naming with the existing set_dc_* convention
    - Keep already-correct button IDs unchanged
    [r4875g1-3phase-charger.yaml]
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2026-08-22 Rename daily energy sensors for clarity
    - Rename AC Energy Total to AC Energy Today
    - Rename DC Energy Total to DC Energy Today
    - Remove redundant kWh text from the visible entity names
    - Keep the existing total_daily_energy implementation unchanged
    - Preserve total_increasing state classification for Home Assistant
    - Clarify that both counters accumulate energy since midnight
    - Document the daily reset behavior using the configured SNTP time source
    - Keep CAN-aware combined power sensors as the source for both energy counters
    - Update README documentation to match the renamed entities and daily semantics
    [r4875g1-3phase-charger.yaml]
2026-08-22 Define explicit first-boot setpoint defaults
    - Add explicit initial values to all persistent template number entities
    - Use 53.0 V as the initial active and fallback DC voltage target
    - Use 1 A as the conservative initial active DC current limit
    - Use 1 A as the initial fallback DC current limit
    - Start the AC current limit at 0 A so AC current limiting is disabled by default
    - Start the fan minimum-speed setting at 0 percent
    - Keep the existing 1.0 kW nominal three-unit DC power default
    - Preserve restore_value behavior so stored user settings override first-boot defaults
    - Avoid relying on implicit min_value defaults for fresh installations
    - Normalize restore_value boolean formatting
    - Do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
    [r4875g1-3phase-charger.yaml]
2026-08-22 Simplify MQTT command handling
    - Replace custom MQTT subscribe text sensors with native number command topics
    - Keep all existing external MQTT command topics backward compatible
    - Centralize the custom MQTT command namespace in one substitution
    - Route MQTT commands directly through ESPHome number entities
    - Use ESPHome native numeric parsing and range validation
    - Remove manual atof parsing and duplicate setpoint validation code
    - Remove obsolete internal MQTT command text sensors
    - Disable MQTT entity discovery because Home Assistant uses the native ESPHome API
    - Keep MQTT device discovery enabled for ESPHome API discovery
    - Preserve MQTT state and command transport for external integrati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
    [r4875g1-3phase-charger.yaml]
2026-08-22 Remove unused local charger state global
    - Remove the obsolete charger_local_on global variable
    - Rely exclusively on live CAN-reported rectifier power states
    - Eliminate legacy state tracking that is no longer referenced
    - Keep local start and stop decisions based on power_state_1 through power_state_3
    - Reduce unused configuration and avoid misleading future maintenance
    [r4875g1-3phase-charger.yaml]
2026-08-22 Clean up comments and stale documentation
    - Correct outdated blackstart comments to describe the nominal three-unit power target
    - Remove duplicate watchdog and display timer comments
    - Correct Unit 2 and Unit 3 scaling-factor documentation
    - Clarify that Unit 1 remains the canonical current-scaling source
    - Update Unit 2 and Unit 3 capability refresh log messages
    - Remove obsolete periodic CAN timing comments
    - Correct the documented 30-second DC current refresh interval
    - Fix the AC current-limit protocol description to match the implemented CAN encoding
    - Clean up voltage and current log formatting
    - Remove obsolete generated-style component comments
    - Normalize the remaining Turn Off Uni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
    [r4875g1-3phase-charger.yaml]
2026-08-22 Normalize YAML and protocol formatting
    - Replace restore_value no with explicit false booleans
    - Keep global initial_value entries quoted as required by ESPHome
    - Normalize remaining CAN identifiers to uppercase hexadecimal notation
    - Quote the remaining unquoted Material Design icon values
    - Remove trailing whitespace throughout the ESPHome configuration
    - Align formatting with the conventions already used across the project
    - Preserve all existing runtime behavior and protocol values
    - Keep ESPHome enum and constant capitalization unchanged
    [r4875g1-3phase-charger.yaml]
2026-08-22 Remove unused touchscreen support
    - Remove the commented XPT2046 touchscreen configuration entirely
    - Remove obsolete touchscreen chip-select and interrupt pin references
    - Eliminate the unused GPIO32 and GPIO33 touchscreen assignments
    - Simplify the SPI bus documentation to describe the ILI9488 display only
    - Remove the touchscreen section from the README
    - Remove the touchscreen entry from the README table of contents
    - Remove obsolete touchscreen limitations and GPIO conflict notes
    - Keep the rotary encoder as the only local input interface
    - Preserve the existing TFT, SPI and display configuration unchanged
    - Reduce dead reference configuration and avoid suggesting unsupported hardware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
    [r4875g1-3phase-charger.yaml]
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
